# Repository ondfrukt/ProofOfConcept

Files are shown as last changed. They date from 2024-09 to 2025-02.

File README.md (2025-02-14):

# Phone exchange - Proof of concept
This project aims to create an analog phone exchange for analog phones, supporting both pulse dialing and tone dialing.

This is a learning project and my personal introduction to programming, arduino and electronics. It might end up with a pile of electronic scrap and hundreds of unused disfunctional lines of code, but it will result in a lot of knowledge and a steep learning curve.

The project is coded in C++ and will use a microcontroller with wifi so that the exchange system can be govern or controlled externaly.
I'm using the [KS0835F](docs/KS0835F.pdf) modules for each phone line to monitor if the Phone hook is on or off. Them modul also generates the ring pulses to the line. A MT8816 will handle all Ain and Aout connections so that a single line is only connected to one lime at the time. The setup neads many GPIO-pins so a bucnh of MCP23017 vill be added.

A typical procedure of the system will be as shown below. A more detailed flowshart can be found [hear](docs/PhoneStatusflowshart.drawio.png)
- A hook is lifted, and the status of the line changes from "idle" to "ready."
- A phone number is dialed using pulse dialing or DTMF tones, and the digits are captured by the microcontroller.
- Ring pulses are generated for the dialed line. Once the hook is picked up, the audio lines are connected using the MT8816.
- One of the phone hooks is put down, ending the call. The audio connection is broken, and the statuses are updated accordingly.

## Phone statuses
Every phone is assigned a status for each moment, depending on how the phone is operated.

- Hook - If the phone hook is on or off due to the status
- Timer - If the new status initiate a timer
- Audio -  If a audio is played to the line due to the status (might not be implemented)
- Tone - if a tone is played to the line due to the status (might not be implemented)

| Phone status  | Function | Hook | Timer | Audio | Tone |
| --- | --- | ---- | ----- |---|---|
| idle | Line is not in use | ON | No |
| ready | Line is ready, waiting for inputs | OFF  | Yes |
| puls_dialing  | Rotary dialing in progress | OFF  | Yes |
| tone_dialing  | Tuch-tone dialing in progress | OFF  | Yes |
| busy | Receiving busy signal | OFF  | Yes |
| fail | Line failed to connect | OFF  | Yes |
| ringing | Line is ringing (outgoing call) | OFF  | Yes |
| connected | Call is active | OFF  | No |
| disconnected  | Call has ended, but line not yet idle | OFF  | Yes |
| timeout | Line timed out | OFF  | Yes |
| abandoned | Line was abandoned | OFF  | Yes |
| incoming | Incoming call | ON | No |
| operator | Connected to operator | - | No |

## More features
- Tones are playing when a hook is picked up, during calling, and if a failure occurs. The tones must be generated by the microcontroller in some way and directed to the active lines depending on their status.
- Special audio sounds will be sent out to a certain line if you, for example, dial a secret number or try to reach 112 (911) without knowing that the phones are not connected to the main tele-network.
- Ability to receive calls from outside the network via a 4G receiver. This feature would be quite hard to implement but not impossible.
- A webpage where settings can be adjusted, line status is shown, and maybe traffic logged.
- MQTT server connection where statuses are updated.

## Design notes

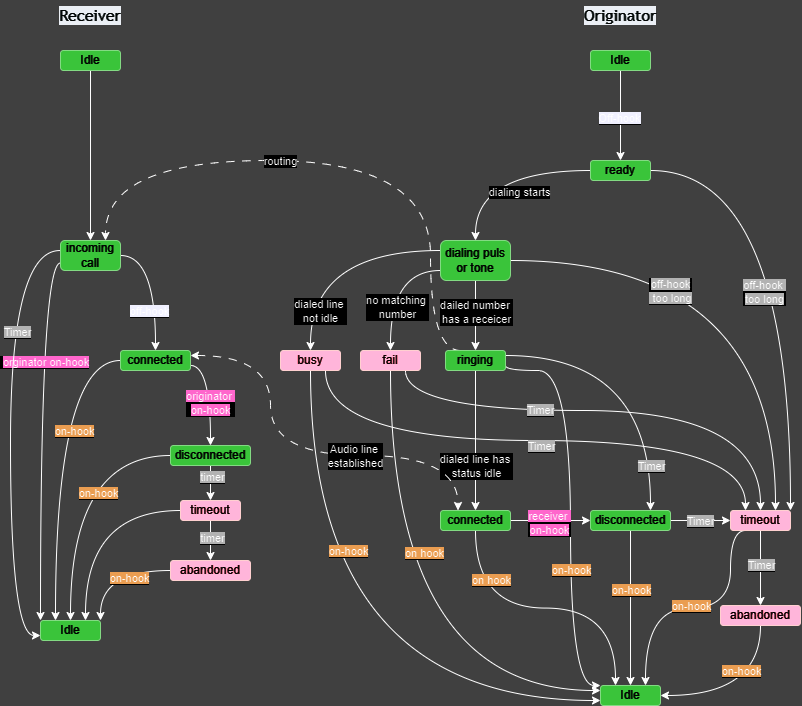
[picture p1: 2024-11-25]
docs/PhoneStatusflowshart.drawio.png

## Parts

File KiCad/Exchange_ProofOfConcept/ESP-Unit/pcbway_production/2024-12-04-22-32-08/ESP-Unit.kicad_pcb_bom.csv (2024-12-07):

Designator | Quantity | Value | Footprint | Package | MPN | DNP | Mount_Type | Description | MF | Description_1 | Price | SnapEDA_Link | MP | Availability | Check_prices | MAXIMUM_PACKAGE_HEIGHT | STANDARD | MANUFACTURER
C1, C4, C5, C6, C8, C9 | 6 | 0,1uF | C_Disc_D5.0mm_W2.5mm_P2.50mm |  |  |  | tht | Unpolarized capacitor
C10, C3 | 2 | 2n2 | C_Disc_D5.0mm_W2.5mm_P2.50mm |  |  |  | tht | Unpolarized capacitor
C2 | 1 | 10uF | C_Disc_D5.0mm_W2.5mm_P2.50mm |  |  |  | tht | Unpolarized capacitor
C7 | 1 | 47uF | CP_Radial_D4.0mm_P2.00mm |  |  |  | tht | Polarized capacitor, US symbol
D1 | 1 | LED | LED_D5.0mm |  |  |  | tht | Light emitting diode
D2, D3, D4, D5 | 4 | LED | LED_D3.0mm |  |  |  | tht | Light emitting diode
H1, H2, H3, H4 | 4 | MountingHole_Pad | MountingHole_3.2mm_M3_Pad_Via |  |  |  | tht | Mounting Hole with connection
IC1 | 1 | MT8870DE | DIP-18_W7.62mm_LongPads | SOIC-18 Microchip |  |  | tht |  | Microsemi Corporation | Telecom IC DTMF Receiver 18-SOIC | None | https://www.snapeda.com/parts/MT8870/Microsemi+Corporation/view-part/?ref=snap | MT8870 | Not in stock | https://www.snapeda.com/parts/MT8870/Microsemi+Corporation/view-part/?ref=eda
J1 | 1 | Jack-DC | BarrelJack_Horizontal |  |  |  | tht | DC Barrel Jack
J2 | 1 | Conn_02x05_Top_Bottom | PinHeader_2x05_P2.54mm_Vertical |  |  |  | tht | Generic connector, double row, 02x05, top/bottom pin numbering scheme (row 1: 1...pins_per_row, row2: pins_per_row+1 ... num_pins), script generated (kicad-library-utils/schlib/autogen/connector/)
J3 | 1 | Conn_01x07 | PinSocket_1x07_P2.54mm_Vertical |  |  |  | tht | Generic connector, single row, 01x07, script generated (kicad-library-utils/schlib/autogen/connector/)
R1 | 1 | 240 | R_Axial_DIN0207_L6.3mm_D2.5mm_P2.54mm_Vertical |  |  |  | tht | Resistor
R10, R11, R8 | 3 | 100K | R_Axial_DIN0207_L6.3mm_D2.5mm_P2.54mm_Vertical |  |  |  | tht | Resistor
R12, R13 | 2 | 4,7K | R_Axial_DIN0207_L6.3mm_D2.5mm_P2.54mm_Vertical |  |  |  | tht | Resistor
R14, R15, R3, R5 | 4 | 10K | R_Axial_DIN0207_L6.3mm_D2.5mm_P2.54mm_Vertical |  |  |  | tht | Resistor
R16, R17, R18 | 3 | 220 | R_Axial_DIN0207_L6.3mm_D2.5mm_P2.54mm_Vertical |  |  |  | tht | Resistor
R2 | 1 | 720 | R_Axial_DIN0207_L6.3mm_D2.5mm_P2.54mm_Vertical |  |  |  | tht | Resistor
R4, R6, R7 | 3 | 470 | R_Axial_DIN0207_L6.3mm_D2.5mm_P2.54mm_Vertical |  |  |  | tht | Resistor
R9 | 1 | 390K | R_Axial_DIN0207_L6.3mm_D2.5mm_P2.54mm_Vertical |  |  |  | tht | Resistor
TP1, TP2, TP4, TP5 | 4 | TestPoint | TestPoint_Pad_D1.0mm |  |  |  | tht | test point
U1 | 1 | ESP32_NODEMCU | MODULE_ESP32_NODEMCU | Package |  |  | tht |  | AZ Delivery | NodeMCU is an open source loT platform. ESP32 is a series of low cost, low power system-on-chip (SoC) microcontrollers with integrated Wi-Fi & dual-mode Bluetooth. | None | https://www.snapeda.com/parts/ESP32%20NODEMCU/AZ-Delivery/view-part/?ref=snap | ESP32 NODEMCU | Not in stock | https://www.snapeda.com/parts/ESP32%20NODEMCU/AZ-Delivery/view-part/?ref=eda | 6.6 mm | Manufacturer Recommendations | Espressif Systems
U2 | 1 | LM317_TO-220 | TO-220-3_Vertical |  |  |  | tht | 1.5A 35V Adjustable Linear Regulator, TO-220
U3 | 1 | LM358PE3 | DIP-8_W7.62mm_LongPads | PDIP-8 Texas |  |  | tht |  | Texas Instruments | Dual, 30-V, 700-kHz operational amplifier | None | https://www.snapeda.com/parts/LM358PE3/Texas+Instruments/view-part/?ref=snap | LM358PE3 | In Stock | https://www.snapeda.com/parts/LM358PE3/Texas+Instruments/view-part/?ref=eda
U4, U5 | 2 | TXS0108EPWR | TSSOP-20_4.4x5mm_P0.5mm | TSSOP-20 Texas Instruments |  |  | smt |  | Texas Instruments | 8-bit bidirectional voltage-level shifter for open-drain and push-pull application | None | https://www.snapeda.com/parts/TXS0108EPWR/Texas+Instruments/view-part/?ref=snap | TXS0108EPWR | In Stock | https://www.snapeda.com/parts/TXS0108EPWR/Texas+Instruments/view-part/?ref=eda
Y1 | 1 | 3.579546 | Crystal_HC49-4H_Vertical |  |  |  | tht | Two pin crystal

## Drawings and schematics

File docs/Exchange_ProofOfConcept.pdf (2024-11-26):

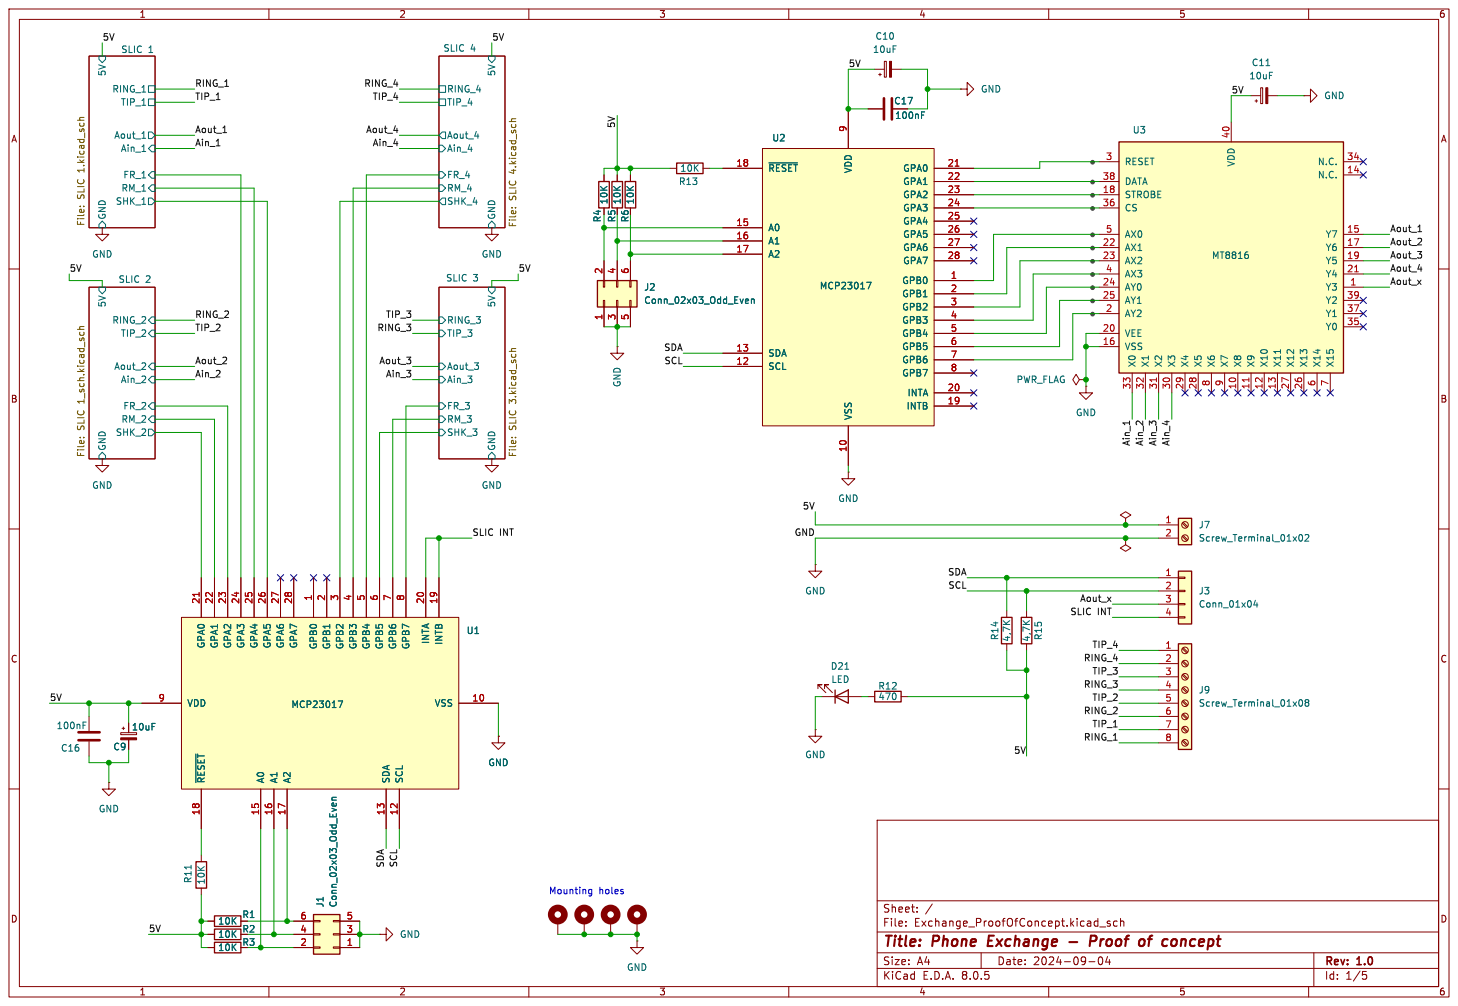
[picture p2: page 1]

5 6 U2 MCP23017 GPB0 1 VSS 10 SCL 12 SDA 13 A0 15 A1 16 A2 17 ~{RESET} 18

1 VSS 10 SCL 12 SDA 13 A0 15 A1 16 A2 17 ~{RESET} 18 INTB 19 GPB1

Id: 1/5 Title: Phone Exchange - Proof of concept File: Exchange_ProofOfConcept.kicad_sch Sheet: /

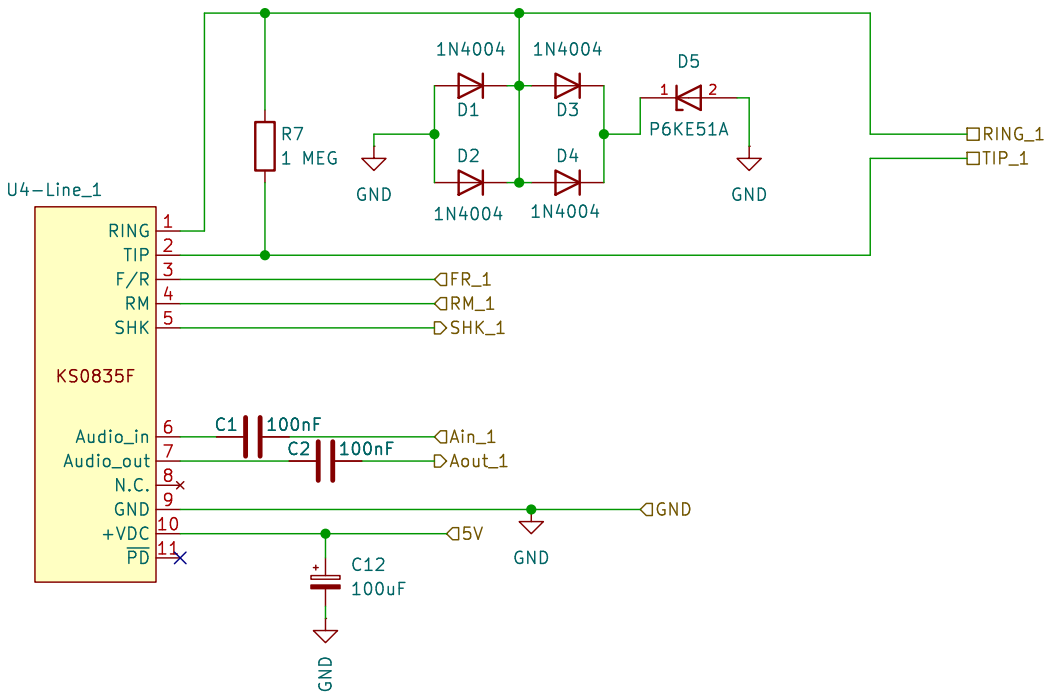
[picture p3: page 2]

Id: 3/5 Title: File: SLIC 1.kicad_sch Sheet: /SLIC 1/

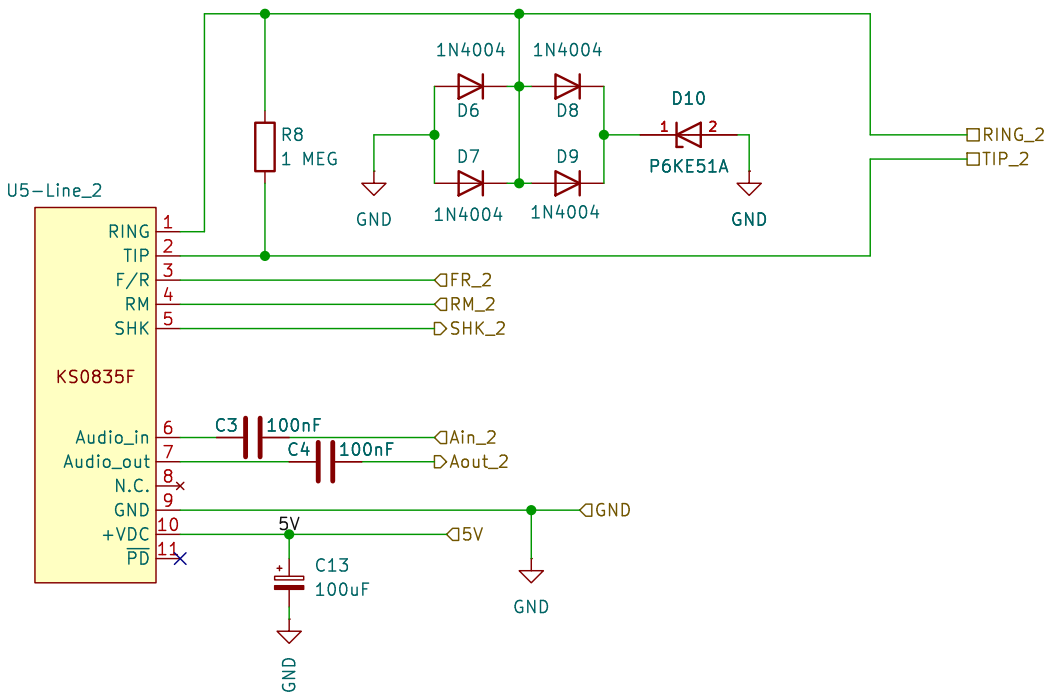
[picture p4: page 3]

Id: 4/5 Title: File: SLIC 1_sch.kicad_sch Sheet: /SLIC 2/

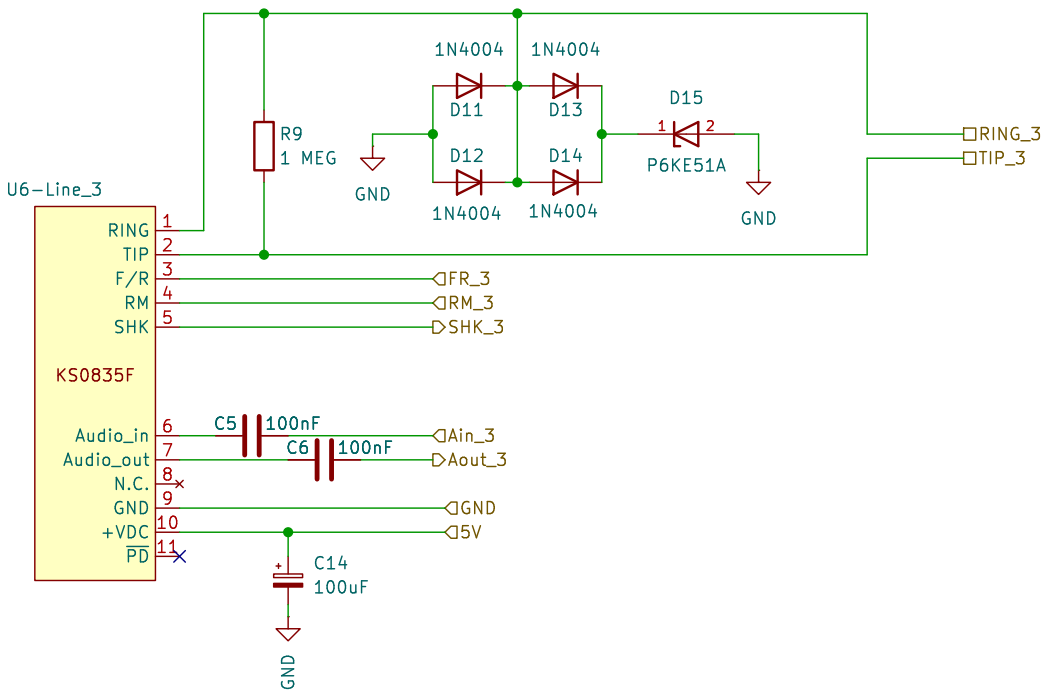
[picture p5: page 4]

Id: 5/5 Title: File: SLIC 3.kicad_sch Sheet: /SLIC 3/ C14

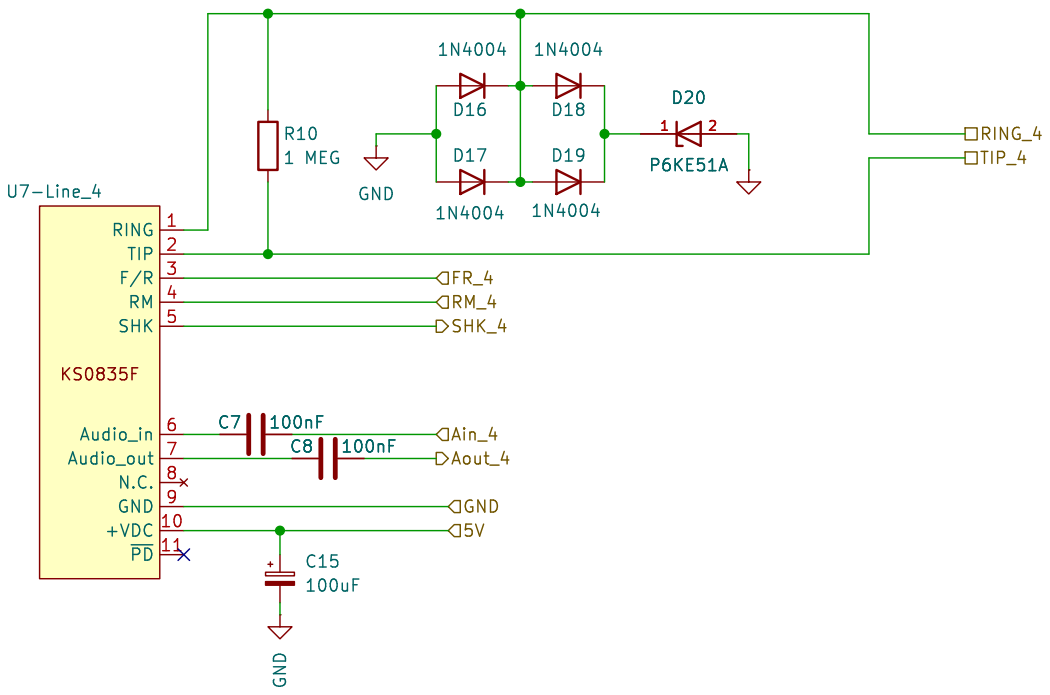
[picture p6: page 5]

Id: 6/5 Title: File: SLIC 4.kicad_sch Sheet: /SLIC 4/

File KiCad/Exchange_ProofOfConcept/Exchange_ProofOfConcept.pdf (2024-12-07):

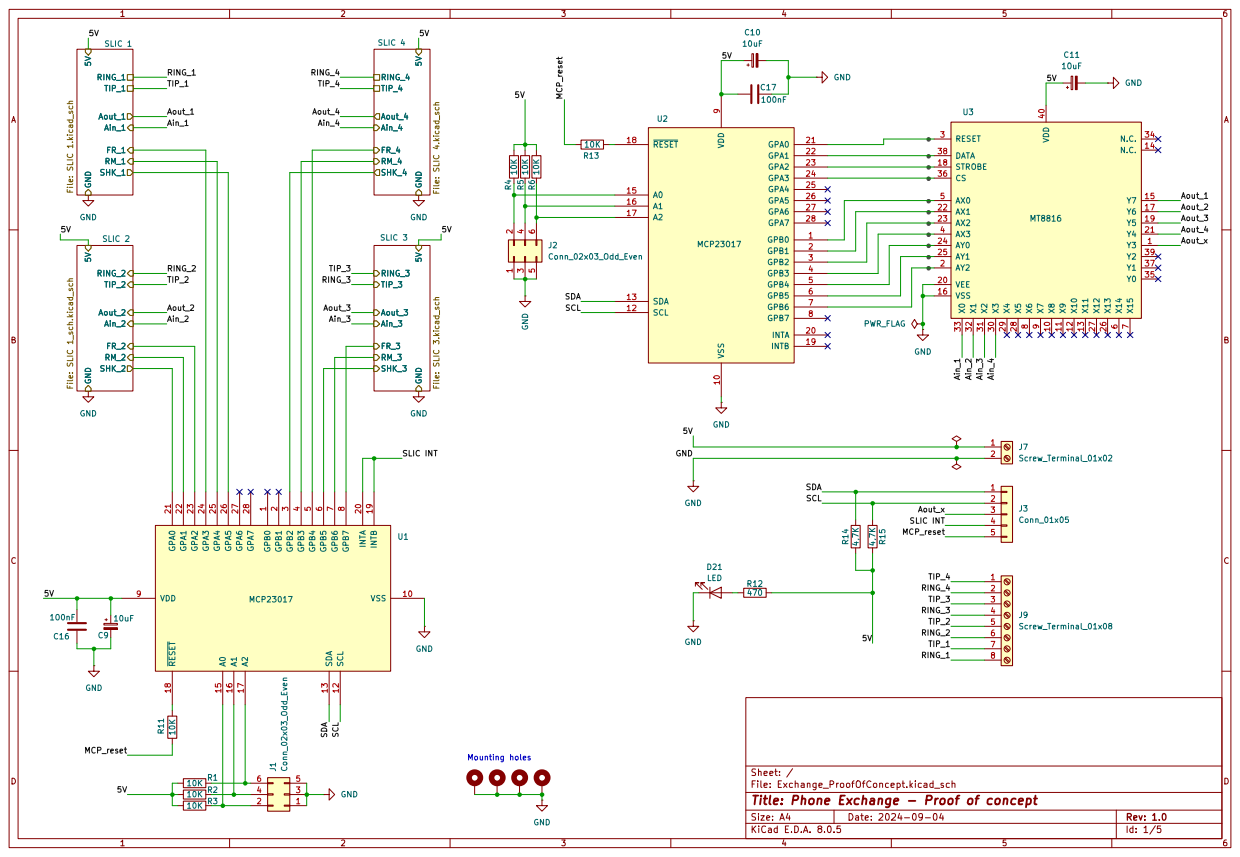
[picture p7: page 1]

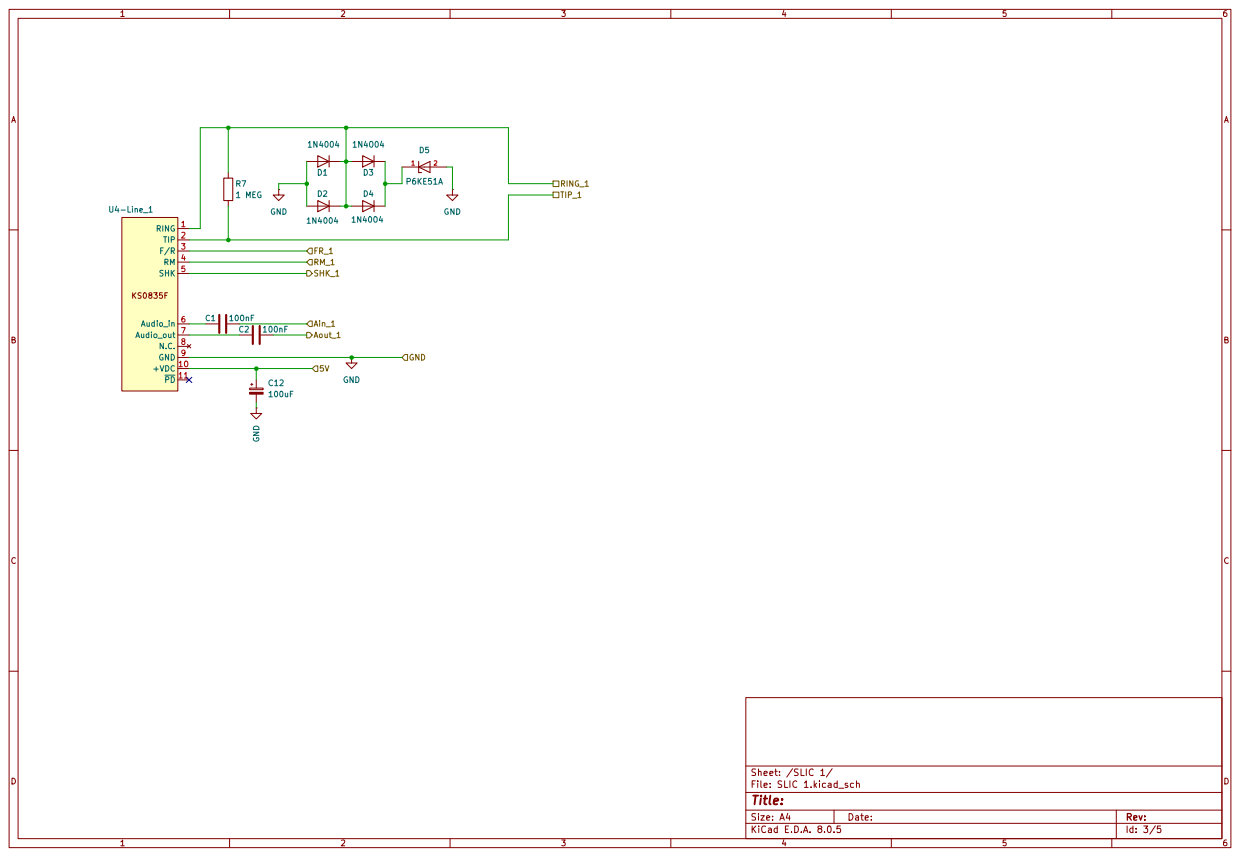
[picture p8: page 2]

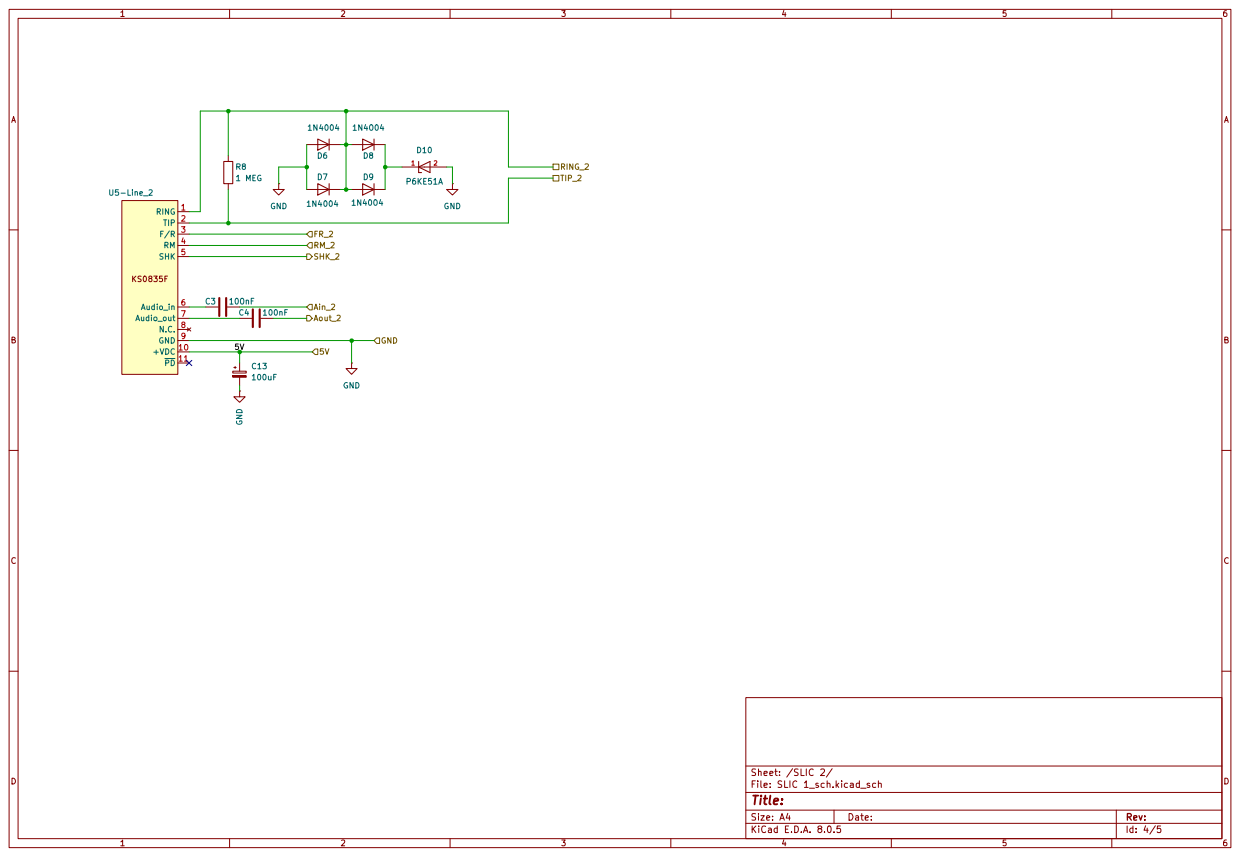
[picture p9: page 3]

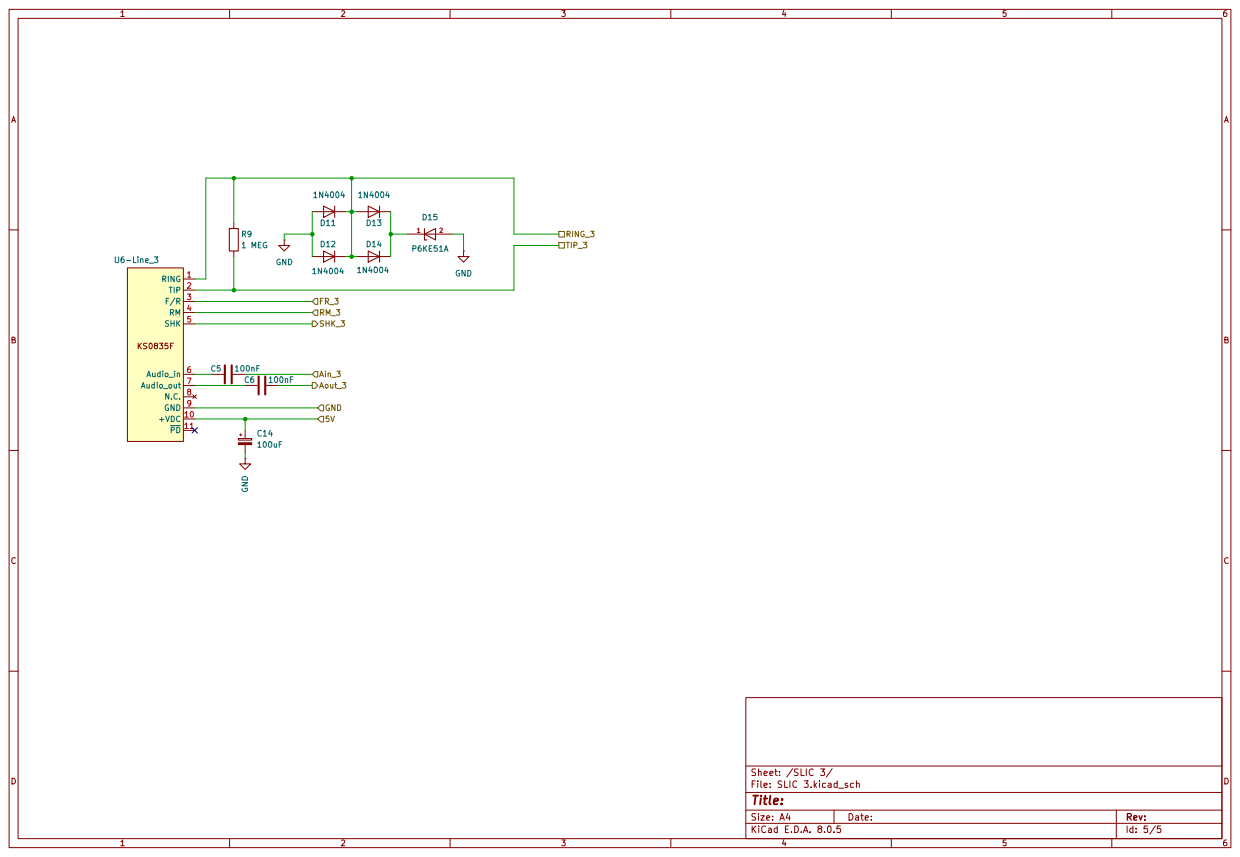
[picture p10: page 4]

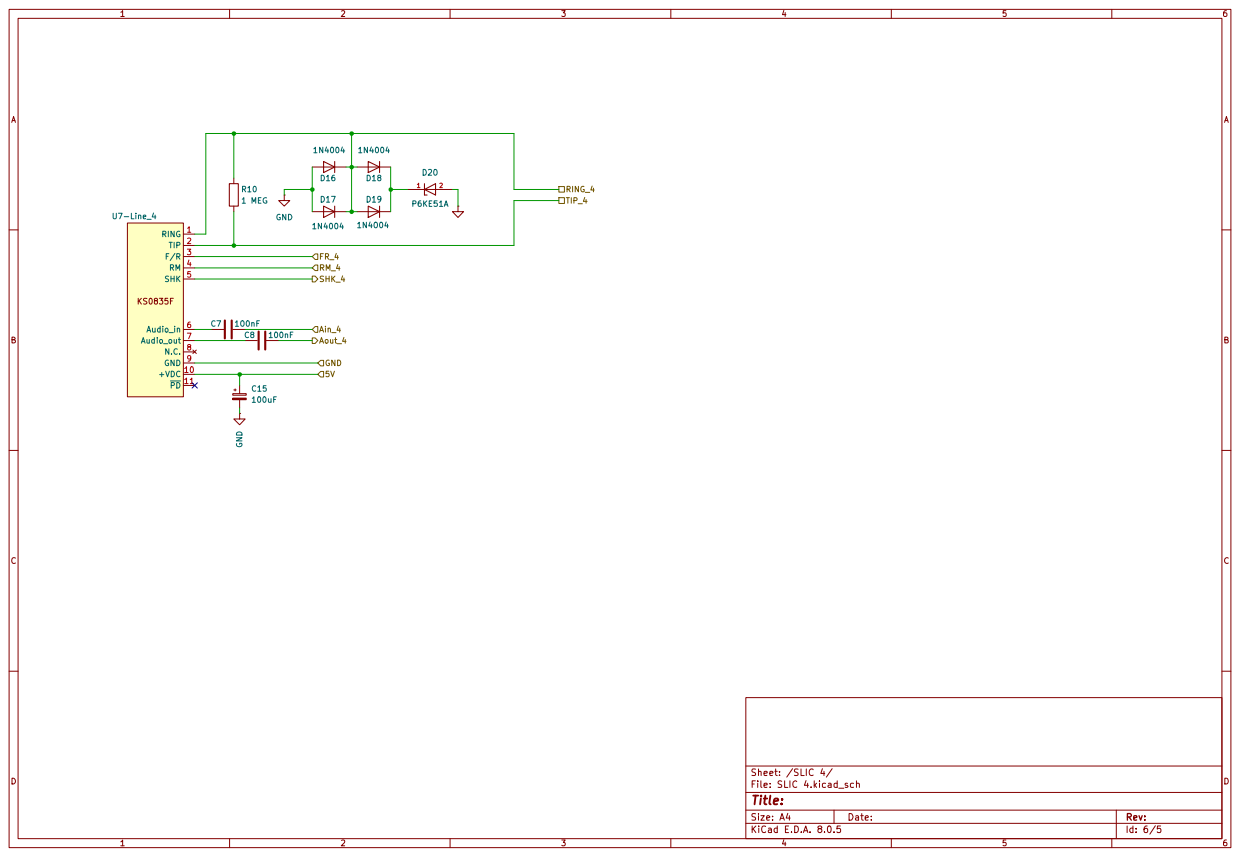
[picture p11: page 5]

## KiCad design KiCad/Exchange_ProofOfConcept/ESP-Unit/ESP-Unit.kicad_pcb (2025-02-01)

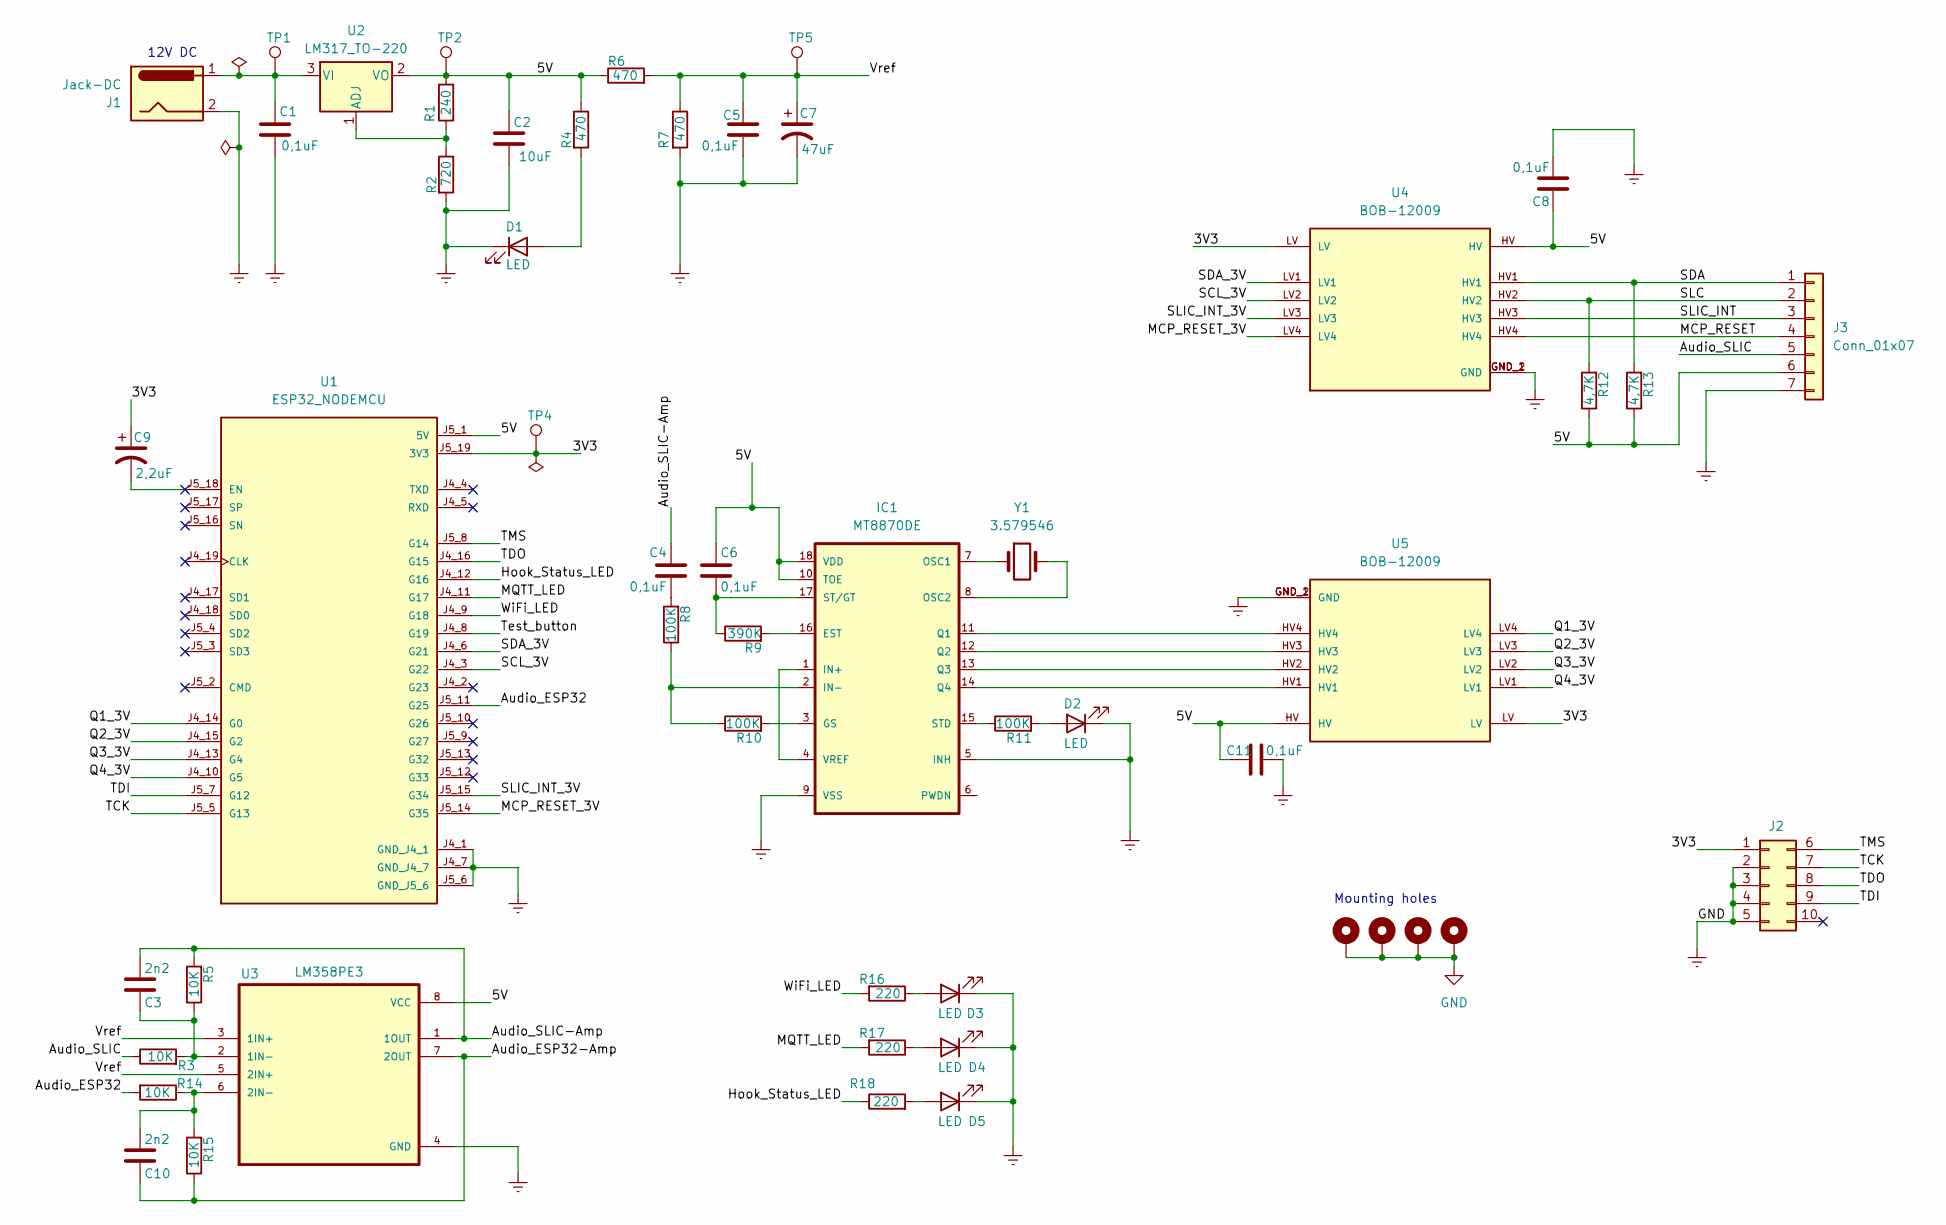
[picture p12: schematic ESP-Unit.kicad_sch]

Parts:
C1, C4, C5, C6, C8, C11: 0,1uF; C_Disc_D5.0mm_W2.5mm_P2.50mm
C2: 10uF; C_Disc_D5.0mm_W2.5mm_P2.50mm
C3, C10: 2n2; C_Disc_D5.0mm_W2.5mm_P2.50mm
C7: 47uF; CP_Radial_D4.0mm_P2.00mm
C9: 2,2uF; CP_Radial_D4.0mm_P2.00mm
D1: LED; LED_D5.0mm
D2, D3, D4, D5: LED; LED_D3.0mm
H1, H2, H3, H4: MountingHole_Pad; MountingHole_3.2mm_M3_Pad_Via
IC1: MT8870DE; DIP-18_W7.62mm_LongPads
J1: Jack-DC; BarrelJack_Horizontal
J2: Conn_02x05_Top_Bottom; PinHeader_2x05_P2.54mm_Vertical
J3: Conn_01x07; PinSocket_1x07_P2.54mm_Vertical
R1: 240; R_Axial_DIN0207_L6.3mm_D2.5mm_P2.54mm_Vertical
R2: 720; R_Axial_DIN0207_L6.3mm_D2.5mm_P2.54mm_Vertical
R3, R5, R14, R15: 10K; R_Axial_DIN0207_L6.3mm_D2.5mm_P2.54mm_Vertical
R4, R6, R7: 470; R_Axial_DIN0207_L6.3mm_D2.5mm_P2.54mm_Vertical
R8, R10, R11: 100K; R_Axial_DIN0207_L6.3mm_D2.5mm_P2.54mm_Vertical
R9: 390K; R_Axial_DIN0207_L6.3mm_D2.5mm_P2.54mm_Vertical
R12, R13: 4,7K; R_Axial_DIN0207_L6.3mm_D2.5mm_P2.54mm_Vertical
R16, R17, R18: 220; R_Axial_DIN0207_L6.3mm_D2.5mm_P2.54mm_Vertical
TP1, TP2, TP4, TP5: TestPoint; TestPoint_Pad_D1.0mm
U1: ESP32_NODEMCU; MODULE_ESP32_NODEMCU
U2: LM317_TO-220; TO-220-3_Vertical
U3: LM358PE3; DIP-8_W7.62mm_LongPads
U4, U5: BOB-12009; CONV_BOB-12009; PARTREV 01
Y1: 3.579546; Crystal_HC49-4H_Vertical

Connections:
/3V3: C9.1, J2.1, TP4.1, U1.J5_19 (3V3), U4.LV, U5.LV
/5V: C2.1, C6.1, C8.2, C11.2, IC1.10 (TOE), IC1.18 (VDD), J3.6, R1.2, R4.1, R6.1, R12.1, R13.1, TP2.1, U1.J5_1 (5V), U2.2 (VO), U3.8 (VCC), U4.HV, U5.HV
/Audio_ESP32: R14.2, U1.J5_11 (G25)
/Audio_ESP32-Amp: C10.2, R15.1, U3.7 (2OUT)
/Audio_SLIC: J3.5, R3.1
/Audio_SLIC-Amp: C3.1, C4.2, R5.2, U3.1 (1OUT)
/Hook_Status_LED: R18.1, U1.J4_12 (G16)
/MCP_RESET: J3.4, U4.HV4
/MCP_RESET_3V: U1.J5_14 (G35), U4.LV4
/MQTT_LED: R17.2, U1.J4_11 (G17)
/Q1_3V: U1.J4_14 (G0), U5.LV4
/Q2_3V: U1.J4_15 (G2), U5.LV3
/Q3_3V: U1.J4_13 (G4), U5.LV2
/Q4_3V: U1.J4_10 (G5), U5.LV1
/SCL_3V: U1.J4_3 (G22), U4.LV2
/SDA: J3.1, R13.2, U4.HV1
/SDA_3V: U1.J4_6 (G21), U4.LV1
/SLC: J3.2, R12.2, U4.HV2
/SLIC_INT: J3.3, U4.HV3
/SLIC_INT_3V: U1.J5_15 (G34), U4.LV3
/TCK: J2.7, U1.J5_5 (G13)
/TDI: J2.9, U1.J5_7 (G12)
/TDO: J2.8, U1.J4_16 (G15)
/TMS: J2.6, U1.J5_8 (G14)
/Test_button: U1.J4_8 (G19)
/Vref: C5.2, C7.1, R6.2, R7.1, TP5.1, U3.3 (1IN+), U3.5 (2IN+)
/WiFi_LED: R16.2, U1.J4_9 (G18)
Earth: C1.2, C2.2, C5.1, C7.2, C8.1, C11.1, D1.1 (K), D2.1 (K), D3.1 (K), D4.1 (K), D5.1 (K), H1.1, H2.1, H3.1, H4.1, IC1.5 (INH), IC1.9 (VSS), J1.2, J2.2, J2.3, J2.4, J2.5, J3.7, R2.2, R7.2, U1.J4_1 (GND_J4_1), U1.J4_7 (GND_J4_7), U1.J5_6 (GND_J5_6), U3.4 (GND), U4.GND_1 (GND), U4.GND_2 (GND), U5.GND_1 (GND), U5.GND_2 (GND)
unnamed: C4.1, R8.2
unnamed: D1.2 (A), R4.2
unnamed: D2.2 (A), R11.2
unnamed: D3.2 (A), R16.1
unnamed: D4.2 (A), R17.1
unnamed: D5.2 (A), R18.2
unnamed: IC1.16 (EST), R9.2
unnamed: IC1.3 (GS), R10.2
unnamed: IC1.1 (IN+), IC1.4 (VREF)
unnamed: IC1.2 (IN-), R8.1, R10.1
unnamed: IC1.7 (OSC1), Y1.1
unnamed: IC1.8 (OSC2), Y1.2
unnamed: IC1.11 (Q1), U5.HV4
unnamed: IC1.12 (Q2), U5.HV3
unnamed: IC1.13 (Q3), U5.HV2
unnamed: IC1.14 (Q4), U5.HV1
unnamed: IC1.15 (STD), R11.1
unnamed: C6.2, IC1.17 (ST/GT), R9.1
unnamed: R1.1, R2.1, U2.1 (ADJ)
unnamed: C1.1, J1.1, TP1.1, U2.3 (VI)
unnamed: C3.2, R3.2, R5.1, U3.2 (1IN-)
unnamed: C10.1, R14.1, R15.2, U3.6 (2IN-)

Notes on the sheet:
Mounting holes
12V DC

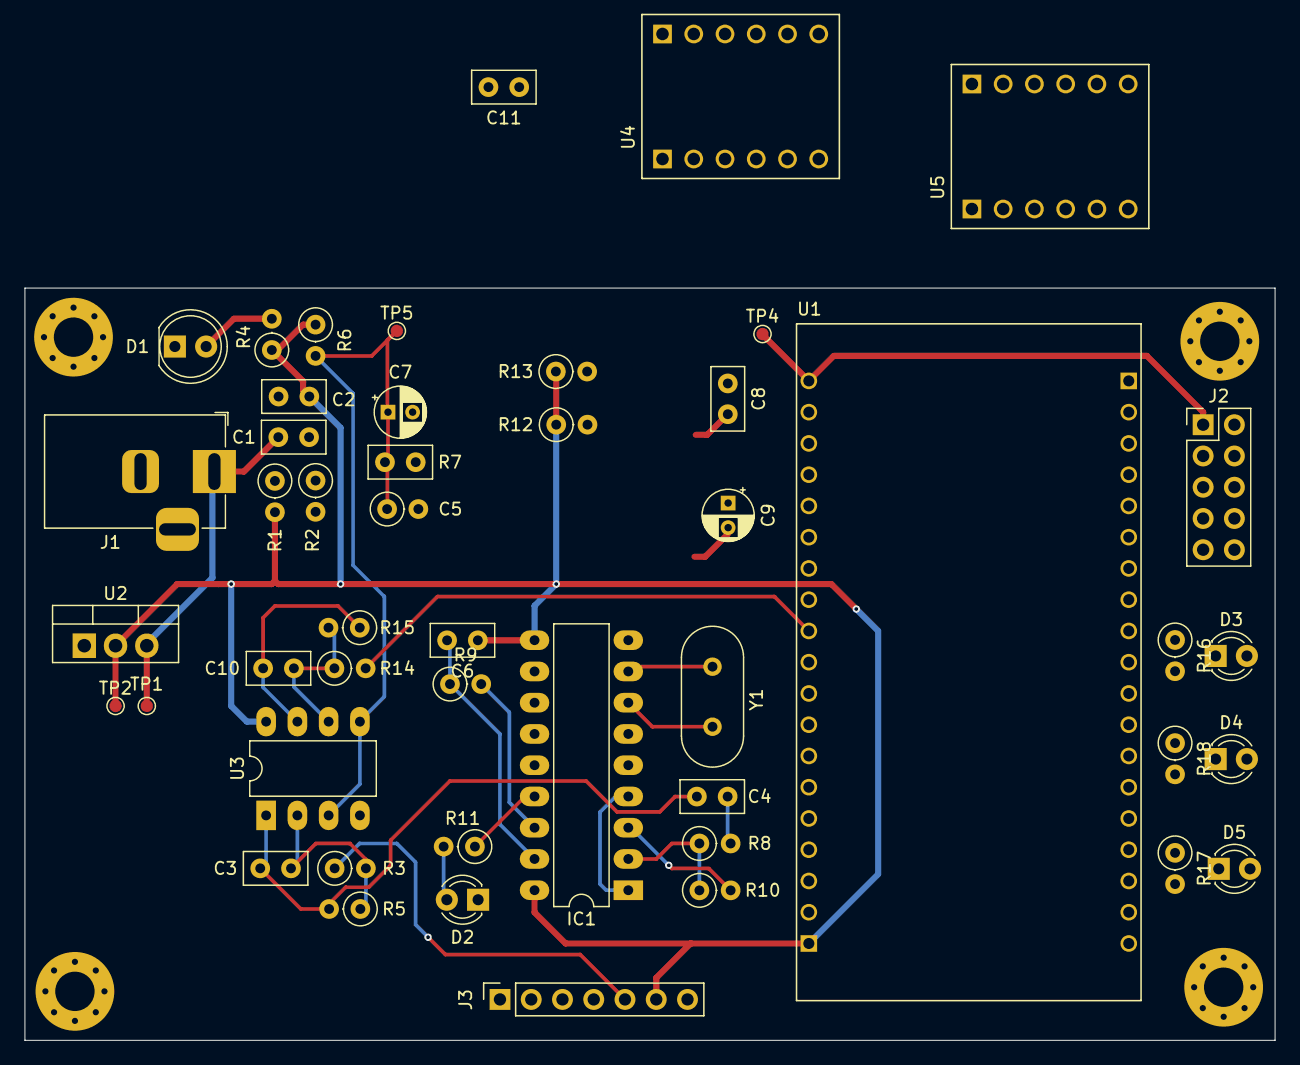
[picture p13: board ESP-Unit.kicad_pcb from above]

Board: 2 copper layers, 101.6 x 61.1 mm, 52 parts (0 on the bottom side), 49 nets.

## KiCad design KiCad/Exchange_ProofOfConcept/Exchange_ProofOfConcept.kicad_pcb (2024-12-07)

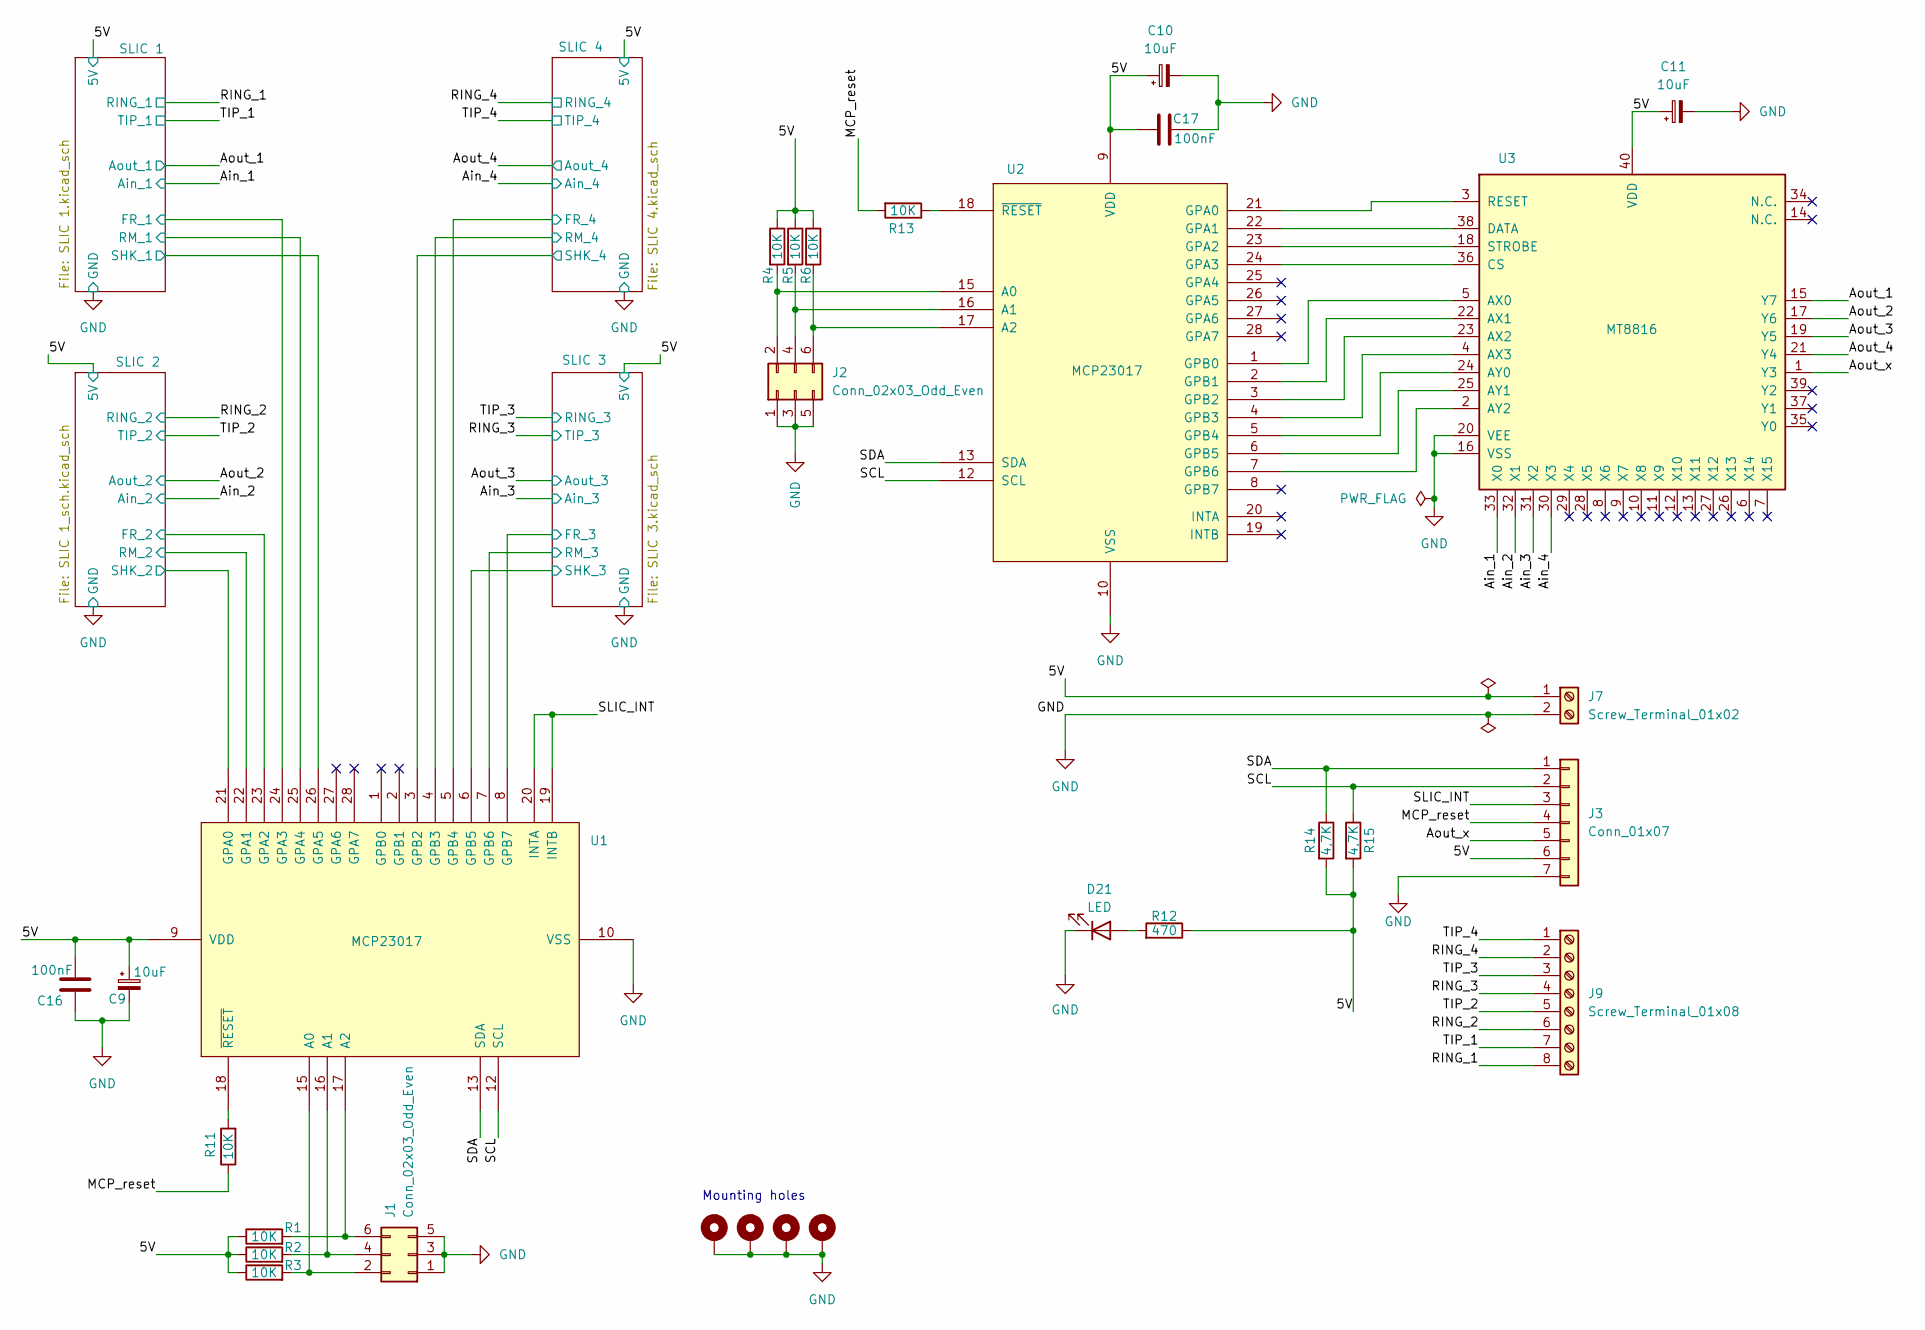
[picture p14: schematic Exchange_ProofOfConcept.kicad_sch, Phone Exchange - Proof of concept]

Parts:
C9, C10, C11: 10uF; CP_Radial_D4.0mm_P2.00mm
C16, C17: 100nF; C_Disc_D5.0mm_W2.5mm_P2.50mm
D21: LED; LED_D5.0mm
H1, H2, H3, H4: MountingHole_Pad; MountingHole_3.2mm_M3_Pad_Via
J1, J2: Conn_02x03_Odd_Even; PinHeader_2x03_P2.54mm_Vertical
J3: Conn_01x07; PinSocket_1x07_P2.54mm_Vertical
J7: Screw_Terminal_01x02; TerminalBlock_Phoenix_MKDS-1,5-2-5.08_1x02_P5.08mm_Horizont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
J9: Screw_Terminal_01x08; TerminalBlock_Phoenix_MKDS-1,5-8_1x08_P5.00mm_Horizontal
R1, R2, R3, R4, R5, R6, R11, R13: 10K; R_Axial_DIN0207_L6.3mm_D2.5mm_P2.54mm_Vertical
R12: 470; R_Axial_DIN0207_L6.3mm_D2.5mm_P2.54mm_Vertical
R14, R15: 4,7K; R_Axial_DIN0207_L6.3mm_D2.5mm_P2.54mm_Vertical
U1, U2: MCP23017; DIP-28_W7.62mm_Socket
U3: MT8816; DIP-40_W15.24mm_Socket_LongPads

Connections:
/5V: C9.1, C10.1, C11.1, C16.2, C17.1, J3.6, J7.1, R1.1, R2.1, R3.1, R4.1, R5.1, R6.1, R12.1, R14.2, R15.2, U1.9 (VDD), U2.9 (VDD), U3.40 (VDD); also elsewhere on the board
/Ain_1: U3.33 (X0); also elsewhere on the board
/Ain_2: U3.32 (X1); also elsewhere on the board
/Ain_3: U3.31 (X2); also elsewhere on the board
/Ain_4: U3.30 (X3); also elsewhere on the board
/Aout_1: U3.15 (Y7); also elsewhere on the board
/Aout_2: U3.17 (Y6); also elsewhere on the board
/Aout_3: U3.19 (Y5); also elsewhere on the board
/Aout_4: U3.21 (Y4); also elsewhere on the board
/Aout_x: J3.5, U3.1 (Y3)
/MCP_reset: J3.4, R11.1, R13.2
/RING_1: J9.8; also elsewhere on the board
/RING_2: J9.6; also elsewhere on the board
/RING_3: J9.4; also elsewhere on the board
/RING_4: J9.2; also elsewhere on the board
/SCL: J3.2, R15.1, U1.12 (SCL), U2.12 (SCL)
/SDA: J3.1, R14.1, U1.13 (SDA), U2.13 (SDA)
/SLIC 1/FR_1: U1.24 (GPA3); also elsewhere on the board
/SLIC 1/RM_1: U1.25 (GPA4); also elsewhere on the board
/SLIC 1/SHK_1: U1.26 (GPA5); also elsewhere on the board
/SLIC 2/FR_2: U1.23 (GPA2); also elsewhere on the board
/SLIC 2/RM_2: U1.22 (GPA1); also elsewhere on the board
/SLIC 2/SHK_2: U1.21 (GPA0); also elsewhere on the board
/SLIC 3/FR_3: U1.8 (GPB7); also elsewhere on the board
/SLIC 3/RM_3: U1.7 (GPB6); also elsewhere on the board
/SLIC 3/SHK_3: U1.6 (GPB5); also elsewhere on the board
/SLIC 4/FR_4: U1.5 (GPB4); also elsewhere on the board
/SLIC 4/RM_4: U1.4 (GPB3); also elsewhere on the board
/SLIC 4/SHK_4: U1.3 (GPB2); also elsewhere on the board
/SLIC_INT: J3.3, U1.19 (INTB), U1.20 (INTA)
/TIP_1: J9.7; also elsewhere on the board
/TIP_2: J9.5; also elsewhere on the board
/TIP_3: J9.3; also elsewhere on the board
/TIP_4: J9.1; also elsewhere on the board
GND: C9.2, C10.2, C11.2, C16.1, C17.2, D21.1 (K), H1.1, H2.1, H3.1, H4.1, J1.1, J1.3, J1.5, J2.1, J2.3, J2.5, J3.7, J7.2, U1.10 (VSS), U2.10 (VSS), U3.16 (VSS), U3.20 (VEE); also elsewhere on the board
unnamed: D21.2 (A), R12.2
unnamed: J1.2, R3.2, U1.15 (A0)
unnamed: J1.4, R2.2, U1.16 (A1)
unnamed: J1.6, R1.2, U1.17 (A2)
unnamed: J2.2, R4.2, U2.15 (A0)
unnamed: J2.4, R5.2, U2.16 (A1)
unnamed: J2.6, R6.2, U2.17 (A2)
unnamed: R11.2, U1.18 (~RESET)
unnamed: U2.21 (GPA0), U3.3 (RESET)
unnamed: U2.22 (GPA1), U3.38 (DATA)
unnamed: U2.23 (GPA2), U3.18 (STROBE)
unnamed: U2.24 (GPA3), U3.36 (CS)
unnamed: U2.1 (GPB0), U3.5 (AX0)
unnamed: U2.2 (GPB1), U3.22 (AX1)
unnamed: U2.3 (GPB2), U3.23 (AX2)
unnamed: U2.4 (GPB3), U3.4 (AX3)
unnamed: U2.5 (GPB4), U3.24 (AY0)
unnamed: U2.6 (GPB5), U3.25 (AY1)
unnamed: U2.7 (GPB6), U3.2 (AY2)
unnamed: R13.1, U2.18 (~RESET)

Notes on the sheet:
Mounting holes

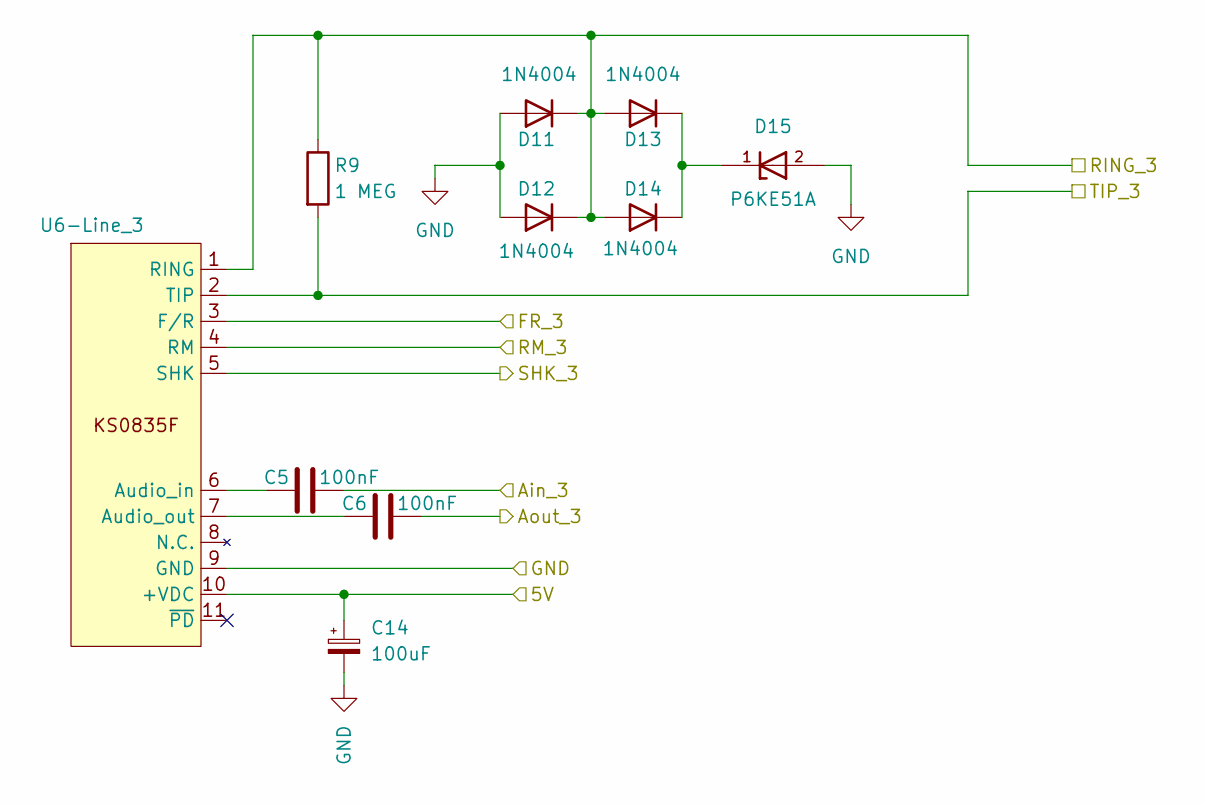
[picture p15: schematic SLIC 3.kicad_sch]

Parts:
C5, C6: 100nF; C_Disc_D4.3mm_W1.9mm_P5.00mm
C14: 100uF; CP_Radial_D5.0mm_P2.00mm
D11, D12, D13, D14: 1N4004; D_DO-41_SOD81_P10.16mm_Horizontal
D15: P6KE51A; D_DO-15_P12.70mm_Horizontal; PARTREV K2105
R9: 1 MEG; R_Axial_DIN0207_L6.3mm_D2.5mm_P2.54mm_Vertical
U6-Line_3: KS0835F

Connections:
/5V: C14.1, U6-Line_3.10 (+VDC); also elsewhere on the board
/Ain_3: C5.2; also elsewhere on the board
/Aout_3: C6.2; also elsewhere on the board
/RING_3: R9.2, U6-Line_3.2 (TIP); also elsewhere on the board
/SLIC 3/FR_3: U6-Line_3.3 (F/R); also elsewhere on the board
/SLIC 3/RM_3: U6-Line_3.4 (RM); also elsewhere on the board
/SLIC 3/SHK_3: U6-Line_3.5 (SHK); also elsewhere on the board
/TIP_3: D11.1 (K), D12.1 (K), D13.2 (A), D14.2 (A), R9.1, U6-Line_3.1 (RING); also elsewhere on the board
GND: C14.2, D11.2 (A), D12.2 (A), D15.2, U6-Line_3.9 (GND); also elsewhere on the board
unnamed: D13.1 (K), D14.1 (K), D15.1
unnamed: C5.1, U6-Line_3.6 (Audio_in)
unnamed: C6.1, U6-Line_3.7 (Audio_out)

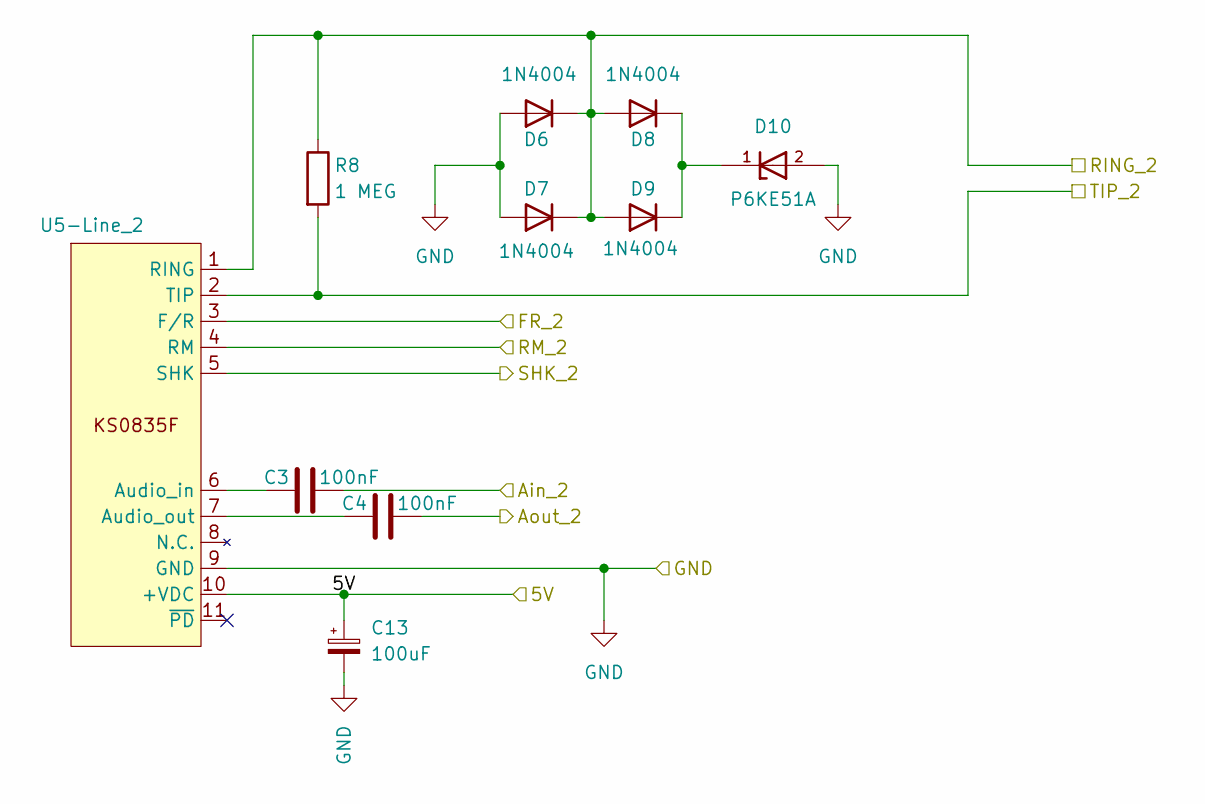
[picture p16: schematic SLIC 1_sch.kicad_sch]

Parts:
C3, C4: 100nF; C_Disc_D4.3mm_W1.9mm_P5.00mm
C13: 100uF; CP_Radial_D5.0mm_P2.00mm
D6, D7, D8, D9: 1N4004; D_DO-41_SOD81_P10.16mm_Horizontal
D10: P6KE51A; D_DO-15_P12.70mm_Horizontal; PARTREV K2105
R8: 1 MEG; R_Axial_DIN0207_L6.3mm_D2.5mm_P2.54mm_Vertical
U5-Line_2: KS0835F

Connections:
/5V: C13.1, U5-Line_2.10 (+VDC); also elsewhere on the board
/Ain_2: C3.2; also elsewhere on the board
/Aout_2: C4.2; also elsewhere on the board
/RING_2: D6.1 (K), D7.1 (K), D8.2 (A), D9.2 (A), R8.1, U5-Line_2.1 (RING); also elsewhere on the board
/SLIC 2/FR_2: U5-Line_2.3 (F/R); also elsewhere on the board
/SLIC 2/RM_2: U5-Line_2.4 (RM); also elsewhere on the board
/SLIC 2/SHK_2: U5-Line_2.5 (SHK); also elsewhere on the board
/TIP_2: R8.2, U5-Line_2.2 (TIP); also elsewhere on the board
GND: C13.2, D6.2 (A), D7.2 (A), D10.2, U5-Line_2.9 (GND); also elsewhere on the board
unnamed: D8.1 (K), D9.1 (K), D10.1
unnamed: C3.1, U5-Line_2.6 (Audio_in)
unnamed: C4.1, U5-Line_2.7 (Audio_out)

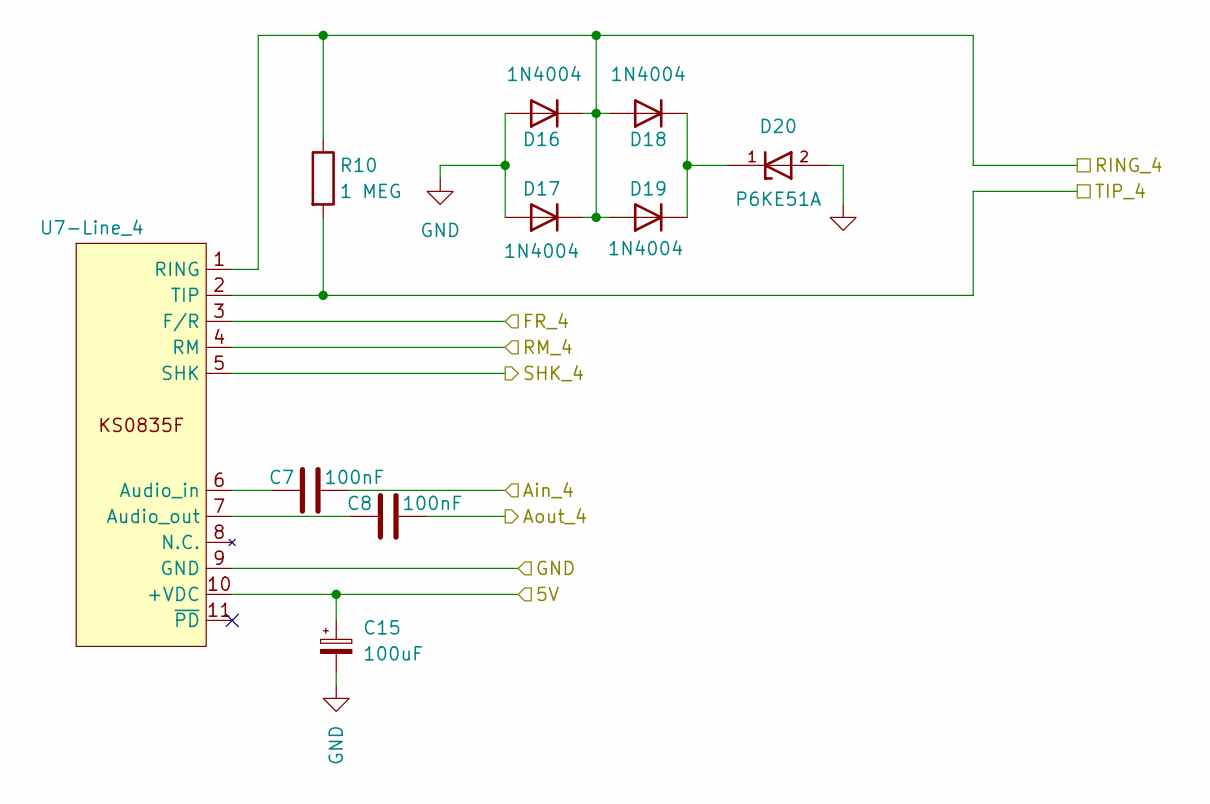
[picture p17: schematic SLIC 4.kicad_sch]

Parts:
C7, C8: 100nF; C_Disc_D4.3mm_W1.9mm_P5.00mm
C15: 100uF; CP_Radial_D5.0mm_P2.00mm
D16, D17, D18, D19: 1N4004; D_DO-41_SOD81_P10.16mm_Horizontal
D20: P6KE51A; D_DO-15_P12.70mm_Horizontal; PARTREV K2105
R10: 1 MEG; R_Axial_DIN0207_L6.3mm_D2.5mm_P2.54mm_Vertical
U7-Line_4: KS0835F

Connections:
/5V: C15.1, U7-Line_4.10 (+VDC); also elsewhere on the board
/Ain_4: C7.2; also elsewhere on the board
/Aout_4: C8.2; also elsewhere on the board
/RING_4: D16.1 (K), D17.1 (K), D18.2 (A), D19.2 (A), R10.1, U7-Line_4.1 (RING); also elsewhere on the board
/SLIC 4/FR_4: U7-Line_4.3 (F/R); also elsewhere on the board
/SLIC 4/RM_4: U7-Line_4.4 (RM); also elsewhere on the board
/SLIC 4/SHK_4: U7-Line_4.5 (SHK); also elsewhere on the board
/TIP_4: R10.2, U7-Line_4.2 (TIP); also elsewhere on the board
GND: C15.2, D16.2 (A), D17.2 (A), D20.2, U7-Line_4.9 (GND); also elsewhere on the board
unnamed: D18.1 (K), D19.1 (K), D20.1
unnamed: C7.1, U7-Line_4.6 (Audio_in)
unnamed: C8.1, U7-Line_4.7 (Audio_out)

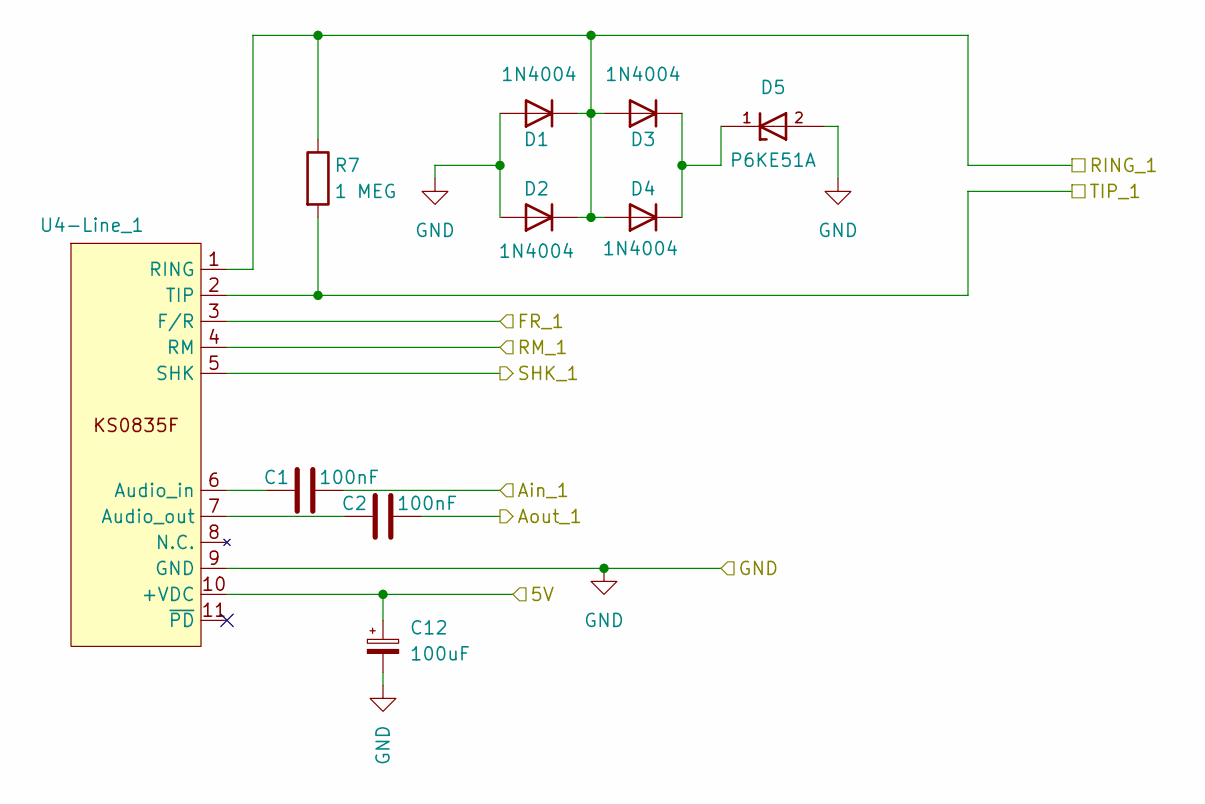
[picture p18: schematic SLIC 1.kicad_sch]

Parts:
C1, C2: 100nF; C_Disc_D4.3mm_W1.9mm_P5.00mm
C12: 100uF; CP_Radial_D5.0mm_P2.00mm
D1, D2, D3, D4: 1N4004; D_DO-41_SOD81_P10.16mm_Horizontal
D5: P6KE51A; D_DO-15_P12.70mm_Horizontal; PARTREV K2105
R7: 1 MEG; R_Axial_DIN0207_L6.3mm_D2.5mm_P2.54mm_Vertical
U4-Line_1: KS0835F

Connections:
/5V: C12.1, U4-Line_1.10 (+VDC); also elsewhere on the board
/Ain_1: C1.2; also elsewhere on the board
/Aout_1: C2.2; also elsewhere on the board
/RING_1: D1.1 (K), D2.1 (K), D3.2 (A), D4.2 (A), R7.1, U4-Line_1.1 (RING); also elsewhere on the board
/SLIC 1/FR_1: U4-Line_1.3 (F/R); also elsewhere on the board
/SLIC 1/RM_1: U4-Line_1.4 (RM); also elsewhere on the board
/SLIC 1/SHK_1: U4-Line_1.5 (SHK); also elsewhere on the board
/TIP_1: R7.2, U4-Line_1.2 (TIP); also elsewhere on the board
GND: C12.2, D1.2 (A), D2.2 (A), D5.2, U4-Line_1.9 (GND); also elsewhere on the board
unnamed: D3.1 (K), D4.1 (K), D5.1
unnamed: C1.1, U4-Line_1.6 (Audio_in)
unnamed: C2.1, U4-Line_1.7 (Audio_out)

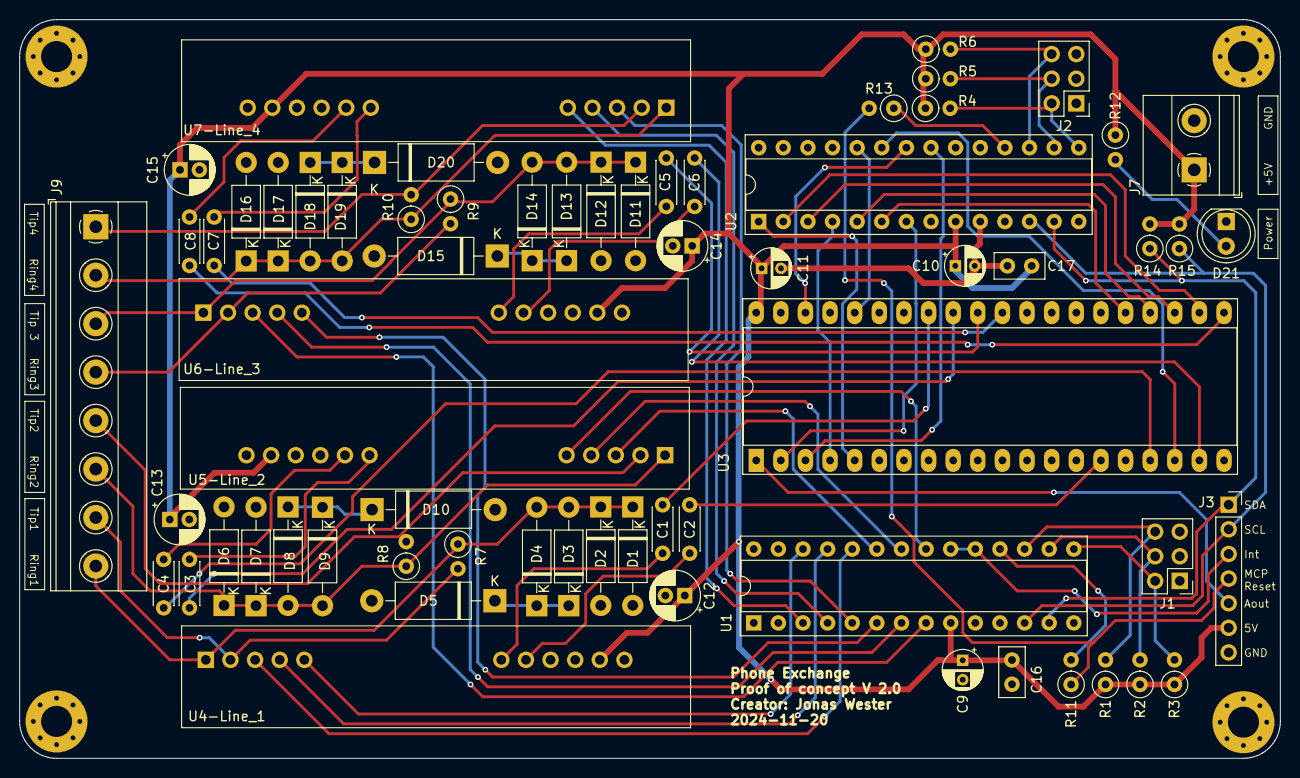
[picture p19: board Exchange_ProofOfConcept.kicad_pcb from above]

Board: 2 copper layers, 130.0 x 76.2 mm, 69 parts (0 on the bottom side), 67 nets.

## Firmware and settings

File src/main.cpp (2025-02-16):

#include <Arduino.h>
#include "config.h"

#include "lineAction.h"
#include "pulsHandler.h"
#include "SHKHandler.h"
#include "toneHandler.h"


#include "LineHandler.h"
#include "mqttHandler.h"


void setup() {
  Serial.begin(115200);
  Serial.println("Setup started");
  
  Wire.begin();
  i2CScanner();
  setupMCPPins();
  mt8816.begin();
  setupMT8870();

  setupHookChecker();
  //mqttHandler.setupWiFi();
  //mqttHandler.setupMQTT();
  

  // Pin modes
  pinMode(hookLED, OUTPUT);
  digitalWrite(hookLED, LOW);
  pinMode(testButton1, INPUT_PULLUP);

  // Set the action callback for the MQTTHandler. This function will be called when MQTT message is received 
  //mqttHandler.setActionCallback(lineAction);

  // connect all Aout_x to the X-line
  mt8816.connectAout_x();

  Serial.println("Setup complete");
  Serial.println("");
}


void loop() {

  // Handle MQTT messages
  //mqttHandler.loop();

  SHKHandler();

  if (allLinesIdle() == false) {
    timerHandler();
  }

  toneHandler();

  if (digitalRead(testButton1) == LOW) {

    mt8816.printConnections();
    
  }
  delay(1);
}

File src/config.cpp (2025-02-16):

#include "config.h"
#include "lineAction.h"
#include "lineStatuses.h"

//------------------ ESP32 GPIO pins ------------------

// LED-pinnar
const int hookLED = 16;
const int mqttLED = 17;
const int wifiLED = 18;

// Testknapp
const int testButton1 = 19;

// Pin modes
void configLEDPins(){
  pinMode(hookLED, OUTPUT);
  digitalWrite(hookLED, LOW);
  pinMode(testButton1, INPUT_PULLUP);
}

//---------------- MCP23017 GPIO pins ----------------

// MCP23017 logic GPIO-pinns
const uint8_t GPA0 = 0;   //Pin 21 
const uint8_t GPA1 = 1;   //Pin 22
const uint8_t GPA2 = 2;   //Pin 23
const uint8_t GPA3 = 3;   //Pin 24
const uint8_t GPA4 = 4;   //Pin 25
const uint8_t GPA5 = 5;   //Pin 26
const uint8_t GPA6 = 6;   //Pin 27
const uint8_t GPA7 = 7;   //Pin 28
const uint8_t GPB0 = 8;   //Pin 1
const uint8_t GPB1 = 9;   //Pin 2
const uint8_t GPB2 = 10;  //Pin 3
const uint8_t GPB3 = 11;  //Pin 4
const uint8_t GPB4 = 12;  //Pin 5
const uint8_t GPB5 = 13;  //Pin 6
const uint8_t GPB6 = 14;  //Pin 7
const uint8_t GPB7 = 15;  //Pin 8

// KS083F constatns
const uint8_t SHKPins[activeLines] = {GPA3, GPA0, GPB5, GPB2};
const uint8_t RMPins[activeLines] = {GPA4, GPA1, GPB3, GPB6};
const uint8_t FRPins[activeLines] = {GPA5, GPA2, GPB7, GPB4};

// MT8816 constants
const uint8_t RESET = GPA0;
const uint8_t DATA = GPA1;
const uint8_t STROBE = GPA2;
const uint8_t CS = GPA3;

const uint8_t AX0 = GPB0;
const uint8_t AX1 = GPB1;
const uint8_t AX2 = GPB2;
const uint8_t AX3 = GPB3;
const uint8_t AY0 = GPB4;
const uint8_t AY1 = GPB5;
const uint8_t AY2 = GPB6;

const uint8_t ax_pins[4] = {AX0, AX1, AX2, AX3};
const uint8_t ay_pins[3] = {AY0, AY1, AY2};

bool Aout_x = false;

// MT8870 constants
const int Q1 = 26;  // Pin för Q1
const int Q2 = 23;  // Pin för Q2
const int Q3 = 4;   // Pin för Q3
const int Q4 = 5;   // Pin för Q4
const int STD = 33; // Signal detect (StD)

// DTMF-tabell för att mappa binärvärde till rätt tecken
const char dtmf_map[16] = {
  ' ', 
  '1', '2', '3',
  '4', '5', '6', 
  '7', '8', '9',
  '0', '*', '#',
};

// MCP-adresses
const uint8_t mcp_mt8816_address = 0x23;
const uint8_t mcp_ks083f_address = 0x26;

// ------------------ Timers ----------------------

unsigned long statusTimer_Ready = 240000;
unsigned long statusTimer_Dialing = 5000;
unsigned long statusTimer_Ringing = 10000;
unsigned long statusTimer_pulsDialing = 3000;
unsigned long statusTimer_toneDialing = 3000;
unsigned long statusTimer_fail = 30000;
unsigned long statusTimer_disconnected = 60000;
unsigned long statusTimer_timeout = 60000;
unsigned long statusTimer_busy = 1000;

int ringLength = 200; // Ring signal lenght in miliseconds

// ------------------ Globala objekt ------------------

LineHandler Line[activeLines] = {
    LineHandler(0),
    LineHandler(1),
    LineHandler(2),
    LineHandler(3)
};

Adafruit_MCP23X17 mcp_ks083f;
Adafruit_MCP23X17 mcp_mt8816;
MQTTHandler mqttHandler(wifiLED, mqttLED);
MT8816 mt8816(mcp_mt8816, (uint8_t[]){AX0, AX1, AX2, AX3}, (uint8_t[]){AY0, AY1, AY2}, STROBE, DATA, RESET, CS);
RingHandler ringHandler(mcp_ks083f, activeLines, RMPins, FRPins, ringLength);

// ---------------SHK variables--------------------

uint8_t SHKDebouncingTime = 10;       // Debounce time for SHK signals
const unsigned pulseGapMax = 80;      // Max time between digit pulses 
unsigned long edge = 0;               // Timestamp for the last puls edge
const unsigned long gapTimeout = 100; // Timeout for pulsing


// ---------------System variables ---------------

bool error = false;       // Error flag
int lastLineReady = -1;   // Last line that was ready. Used to guess witch line thats sends dtmf tones.

// ------------------ Funktions ------------------

void i2CScanner() {
    byte error, address;
    int nDevices = 0;

    for (address = 1; address < 127; address++) {
        Wire.beginTransmission(address);
        error = Wire.endTransmission();

        if (error == 0) {
            Serial.print("I2C device found at address 0x");
            if (address < 16) Serial.print("0");
            Serial.print(address, HEX);
            Serial.println("  !");
            nDevices++;
        } else if (error == 4) {
            Serial.print("Unknown error at address 0x");
            if (address < 16) Serial.print("0");
            Serial.println(address, HEX);
        }
    }
    
    if (nDevices == 0) {
        Serial.println("No I2C devices found\n");
    } else {
        Serial.println("Scanning done\n");
    }
}
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

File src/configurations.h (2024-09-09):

#include <Arduino.h>

// Setting up MCP for KS083F

#define GPA0 0
#define GPA1 1
#define GPA2 2
#define GPA3 3
#define GPA4 4
#define GPA5 5
#define GPA6 6
#define GPA7 7

#define GPB0 8
#define GPB1 9
#define GPB2 10
#define GPB3 11
#define GPB4 12
#define GPB5 13
#define GPB6 14
#define GPB7 15

const uint8_t SHK_1 = GPA3;
const uint8_t RM_1 = GPA4;
const uint8_t FR_1 = GPA5;

const uint8_t SHK_2 = GPA0;
const uint8_t RM_2 = GPA1;
const uint8_t FR_2 = GPA2;

const uint8_t SHK_3 = GPB4;
const uint8_t RM_3 = GPB3;
const uint8_t FR_3 = GPB2;

const uint8_t SHK_4 = GPB7;
const uint8_t RM_4 = GPB6;
const uint8_t FR_4 = GPB5;


// -----------------SHK--------------------------

// Define the number of digital inputs we want to read
#define NUM_INPUTS 4

// Array to store the pin numbers for each input
const uint8_t inputPins[NUM_INPUTS] = {SHK_1, SHK_2, SHK_3, SHK_4};

// Arrays to store debounce-related information for each input
unsigned long lastDebounceTime[NUM_INPUTS] = {0};  // Last time the input was toggled
int lastInputState[NUM_INPUTS] = {LOW};            // Previous input state
int inputState[NUM_INPUTS] = {LOW};                // Current debounced input state

// SHK Debounce time in milliseconds
uint8_t SHKDebouncing = 50;

// MCP adress
uint8_t mcp2_address = 0;

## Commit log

2024-08-25 modified: src/configurations.h modified: src/main.cpp
    [configurations.h]
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2024-09-09 new file: KiCad/Exchange_ProofOfConcept/Exchange_ProofOfConcept-backups/Exchange_ProofOfConcept-2024-08-25_222411.zip new file: KiCad/Exchange_ProofOfConcept/Exchange_ProofOfConcept-backups/Exchange_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
    [Exchange_ProofOfConcept.kicad_pcb, Exchange_ProofOfConcept.kicad_sch, SLIC 1.kicad_sch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]
2024-09-09 deleted: KiCad/Exchange_ProofOfConcept/Exchange_ProofOfConcept-backups/Exchange_ProofOfConcept-2024-08-25_222411.zip new file: KiCad/Exchange_ProofOfConcept/Exchange_ProofOfConcept-backups/Exchange_P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
    [Exchange_ProofOfConcept.kicad_pcb, configurations.h]
2024-09-09 new file: KiCad/Exchange_ProofOfConcept/~Exchange_ProofOfConcept.kicad_sch.lck new file: docs/FunctionFlow.drawio deleted: "docs/Namnl\303\266st diagram.drawio" deleted: include/configurations.h modi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
    [configurations.h]
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2024-09-22 deleted: KiCad/Exchange_ProofOfConcept/Exchange_ProofOfConcept-backups/Exchange_ProofOfConcept-2024-08-28_233227.zip deleted: KiCad/Exchange_ProofOfConcept/Exchange_ProofOfConcept-backups/Exchange_Pr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
    [Exchange_ProofOfConcept.kicad_V1_pcb.kicad_pcb, Exchange_ProofOfConcept.kicad_pcb, Exchange_ProofOfConcept.kicad_sch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]
2024-09-22 deleted: KiCad/Exchange_ProofOfConcept/Exchange_ProofOfConcept-backups/Exchange_ProofOfConcept-2024-09-22_003036.zip deleted: KiCad/Exchange_ProofOfConcept/Exchange_ProofOfConcept-backups/Exchange_Pr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
    [Exchange_ProofOfConcept.kicad_pcb]
2024-10-02 deleted: KiCad/Exchange_ProofOfConcept/Exchange_ProofOfConcept-backups/Exchange_ProofOfConcept-2024-09-22_005249.zip new file: KiCad/Exchange_ProofOfConcept/Exchange_ProofOfConcept-backups/Exchange_P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
    [Exchange_ProofOfConcept.kicad_pcb, Exchange_ProofOfConcept.kicad_sch]
2024-10-10 deleted: KiCad/Exchange_ProofOfConcept/Exchange_ProofOfConcept-backups/Exchange_ProofOfConcept-2024-09-09_184758.zip new file: KiCad/Exchange_ProofOfConcept/Exchange_ProofOfConcept-backups/Exchange_P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
    [Exchange_ProofOfConcept.kicad_pcb]
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2024-11-17 new file: KiCad/Exchange_ProofOfConcept/ESP-Unit/ESP-Unit-backups/ESP-Unit-2024-10-22_204833.zip new file: KiCad/Exchange_ProofOfConcept/ESP-Unit/ESP-Unit-backups/ESP-Unit-2024-10-22_205851.zip new f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
    [ESP-Unit.kicad_pcb, ESP-Unit.kicad_sch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]
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2024-11-21 deleted: KiCad/Exchange_ProofOfConcept/Exchange_ProofOfConcept-backups/Exchange_ProofOfConcept-2024-09-22_005800.zip deleted: KiCad/Exchange_ProofOfConcept/Exchange_ProofOfConcept-backups/Exchange_Pr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
    [Exchange_ProofOfConcept.kicad_pcb, Exchange_ProofOfConcept.kicad_sch, SLIC 1.kicad_sch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]
2024-11-26 new file: KiCad/Exchange_ProofOfConcept/#auto_saved_files# deleted: KiCad/Exchange_ProofOfConcept/Exchange_ProofOfConcept-backups/Exchange_ProofOfConcept-2024-10-10_194257.zip deleted: KiCad/Exchange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
    [Exchange_ProofOfConcept.kicad_pcb]
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2024-11-28 modified: .gitignore deleted: KiCad/Exchange_ProofOfConcept/#auto_saved_files# deleted: KiCad/Exchange_ProofOfConcept/Exchange_ProofOfConcept-backups/Exchange_ProofOfConcept-2024-10-11_163116.zip new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
    [Exchange_ProofOfConcept.kicad_sch]
2024-12-07 Changes to be committed: new file: KiCad/Exchange_ProofOfConcept/ESP-Unit/ESP-Unit-backups/ESP-Unit-2024-11-30_004013.zip new file: KiCad/Exchange_ProofOfConcept/ESP-Unit/ESP-Unit-backups/ESP-Unit-20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
    [ESP-Unit-B_Cu.gbr, ESP-Unit-B_Mask.gbr, ESP-Unit-B_Paste.gbr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]
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2025-01-14 deleted: KiCad/Exchange_ProofOfConcept/ESP-Unit/#auto_saved_files# modified: KiCad/Exchange_ProofOfConcept/ESP-Unit/ESP-Unit.kicad_sch renamed: KiCad/Exchange_ProofOfConcept/ESP-Unit/_autosave-ESP-Un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
    [ESP-Unit.kicad_sch]
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2025-01-19 deleted: KiCad/Exchange_ProofOfConcept/ESP-Unit/#auto_saved_files# modified: KiCad/Exchange_ProofOfConcept/ESP-Unit/ESP-Unit.kicad_sch deleted: KiCad/Exchange_ProofOfConcept/ESP-Unit/_autosave-ESP-Un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
    [ESP-Unit.kicad_sch]
2025-02-01 deleted: KiCad/Exchange_ProofOfConcept/ESP-Unit/ESP-Unit-backups/ESP-Unit-2024-10-22_204833.zip new file: KiCad/Exchange_ProofOfConcept/ESP-Unit/ESP-Unit-backups/ESP-Unit-2025-01-21_222447.zip new fi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
    [ESP-Unit.kicad_pcb, ESP-Unit.kicad_sch, Exchange_ProofOfConcept.kicad_V1_pcb.kicad_pcb]
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2025-02-15 new file: KiCad/Exchange_ProofOfConcept/ESP-Unit/#auto_saved_files# new file: KiCad/Exchange_ProofOfConcept/ESP-Unit/_autosave-ESP-Unit.kicad_sch modified: KiCad/Exchange_ProofOfConcept/Exchange_Proo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
    [Exchange_ProofOfConcept.kicad_sch]
2025-02-16 modified: KiCad/Exchange_ProofOfConcept/ESP-Unit/ESP-Unit.kicad_sch deleted: KiCad/Exchange_ProofOfConcept/ESP-Unit/_autosave-ESP-Unit.kicad_sch modified: include/config.h new file: include/toneHandl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
    [ESP-Unit.kicad_sch]
2025-02-16 deleted: KiCad/Exchange_ProofOfConcept/#auto_saved_files# deleted: KiCad/Exchange_ProofOfConcept/ESP-Unit/#auto_saved_files# deleted: KiCad/Exchange_ProofOfConcept/Exchange_ProofOfConcept-backups/Exc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
    [Exchange_ProofOfConcept.kicad_sch, SLIC 1.kicad_sch, SLIC 1_sch.kicad_sch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]
